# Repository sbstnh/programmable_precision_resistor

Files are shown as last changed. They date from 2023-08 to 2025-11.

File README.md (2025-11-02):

# Programmable Precision Resistor

A SCPI programmable precision resistor

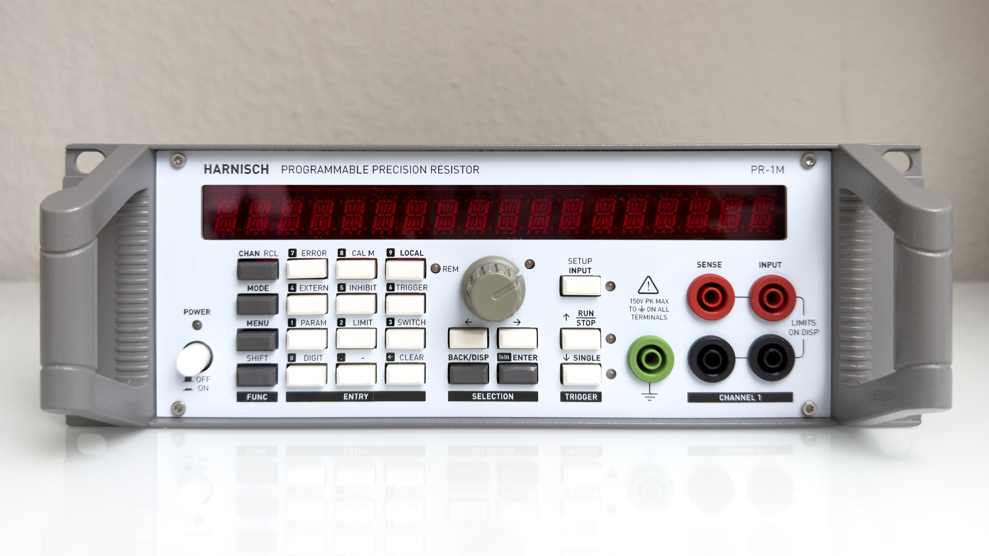
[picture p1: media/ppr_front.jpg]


**WARNING:** The programmable power resistor presented is mains powered. On the power supply board there will be mains/line voltage. Working with/on such devices can lead to damage, injury or death. Don't do it if you're not qualified or authorized to do so. You use the circuits described at you own risk. You have to make sure that the circuit is safe and adheres to the applicable standards in your location. You might operate the mainboard and ui board more safely with a bench or external power supply.

**WARNING:** I abandoned the AC/DC converter of the initial design mostly due to EMI issues. I ended up using a EI-core (isolation) transformer, bridge rectifier, capacitor two tiny DC/DC converters. Some of the documentation does not reflect this change.

## Background and motivation

In 2021/2022 I designed a DC electronic load that would be more capable, but also much more complex than the usual DIY solutions. However, after building a working breadboard prototype of the analog circuitry with 12 ICs including multiple precision and dual opamps, I thought that it might be better to start with a smaller project that would allow me to gain a lot of experience and write much of the non-application specific code that I could use later on for the digital part. Also, at the time I was looking for a decade resistor box to add to my lab. And this is how I started working on a programmable decade resistor, a pretty specialized tool for niche applications.

## Introduction

A programmable resistor is a electronic device whose electrical resistance can be adjusted typically through digital signals. Programmable resistors are available in form of integrated circuits (often referred to as digital potentiometers) as well as stand-alone devices/expansion cards. There are many different applications, each with their own set of requirements e. g.:

programmable gain amplifiers
sensor emulation, e. g. for integration tests with hardware-in-the-loop simulators
automated testing
calibrators
prototyping
Basic concept
The programmable resistor closely follows the main principle of resistor decade boxes: connecting multiple devices (“decades”) in series, with each of the devices having a settable resistance of 0 Ω, 1 ⋅ 10^n Ω, 2 ⋅ 10^n Ω, 9 ⋅ 10^n Ω, where n specifies the decade in question.

Those devices are simple resistor networks complemented by one (multi-throw) or more (single- or multi-throw) switches. While the actual topology and resistor values vary vastly, the switch(es) will always either short out or connect certain resistors or simply tap certain nodes of the resistor network. A simple implementation uses a 10-throw rotary switch to tap the nodes of a series resistor network of nine resistors.

## Features

| Parameter | Value / Description |
| :--- | :--- |
| Range | short circuit, 1 Ω … 999.999 kΩ, open circuit |
| Setpoint resolution | 1 Ω |
| Short-term setpoint accuracy estimate | <=±0.1% of value + 0.15 Ω (2W and 4W). The estimate is based on measurements for a limited number of calibration and validation resistance setpoints. The measurements were performed with an older Agilent 34401A 6.5 digit multimeter for a single DUT. This is NOT a valid strategy to get reliable/reproducible results in the sense of a specification. It's just a more or less plausible envelope based on measurements I took for my prototype. |
| Display value resolution | 6.5 digits, 5.5 digits, 4.5 digits, 3.5 digits, but not better than 1 mΩ |
| Short-term display accuracy estimate | <=±0.01% + 0.025 Ω (2W and 4W). This figure is meant to show how much the displayed resistance value (that is based on a calibration) deviates from the value shown on the DMM, the calibration has been performed with. |
| Thermal drift (estimate based on design) | <<50 ppm/K |
| Power rating | >=0.2W for decade 0 (0..9Ω),<br />>=0.5W else<br />Exact value depends on setpoint (display) |
| Bandwidth | unspecified |
| Calibration modes | - Uncalibrated: Switches are activated according to entered setpoint, display shows setpoint<br />- Two-wire (2W), Four-wire (4W): An internal setpoint is calculated based on the calibration values to reduce the error (effects changes for higher resistance values only) |
| Operating modes | Fixed: On trigger no change<br />Step: On trigger step to trigger setpoint value<br />Up: On trigger increase setpoint (linearly, 1-2-3-4-5-6-7-8-9, 1-2-5, 1-3)<br />Down: On trigger increase setpoint (linearly, 1-2-3-4-5-6-7-8-9, 1-2-5, 1-3)<br />List: See list mode |
| List mode | Up to 100 values with individual dwell times<br />- Start: on trigger; or immediately after mode selection<br />- Step:<br />  - Auto: Advance index automatically, solely based on dwell time<br />  - Trigger: Advance index on each trigger event, ignoring the dwell time<br />  - Once: Advance index on each trigger event, only after dwell time elapsed |
| Switching | fast (default), break-before-make |
| Trigger | Source: Bus, External (Rising, Falling, Either), Immediate, Manual, Timer;<br />Mode: Continuous, Single<br />Parameter: Delay, Holdoff, Time (Source: Timer) |
| Inhibit | Inhibit the input<br />- Latching: Latch input on/off on inhibit input change<br />- Live: Switch input on/off according to present inhibit input state |
| Command and trigger execution | 10ms loops |
| User interface | - 18 digit alphanumeric display:<br />  - Primary display: Resistance setpoint<br />  - Secondary display: Input state, max. current at setpoint, max. voltage at setpoint, max. power at setpoint, hardware setpoint<br />  - Menu-based<br />- 6 dual color LEDs<br />- Rotary encoder with push button<br />- 23 additional push buttons |
| User presets | 0-9; 0 is loaded on power-up |
| Interface | - USB<br />- Two digital inputs, settable polarity (positive, negative) and function (trigger, inhibit, readout) |
| Power supply | Switch mode |

## System design

System block diagram

The block diagram provides an overview of the different circuit groups of each functional block, their internal connections and external interfaces. The Programmable Decade Resistor consists of three main functional blocks:

1. Power supply (Power Supply Board), an external EMI filter is required.
2. Programmable decades, control and driver circuits (Mainboard)
3. User Interface (User Interface Board)

The power supply board uses an off-the-shelve AC/DC converter to provide a +15V rail. The +15V rail powers the relays on the mainboard as well as a DC/DC converter. A single DC/DC converter generates a +3.3V supply for both the mainboard and the UI board, including the LED display. The power rails are earth-referenced. (Nevertheless, the inputs of the Programmable Decade Resistor are floating thanks to the isolation of the relays.)

The mainboard’s main controller contains the business logic to control the relays, read the external inputs and run the USB and user interfaces. The main controller communicates with the User Interface Board over I2C which handles the multiplexing of the alphanumeric LED display, scans the switch matrix, decodes the signals of the rotary encoder and drives the buzzer.

Note that these pictures DO NOT represent the final design of the Programmable Precision Resistor and the power supply circuit in particular.
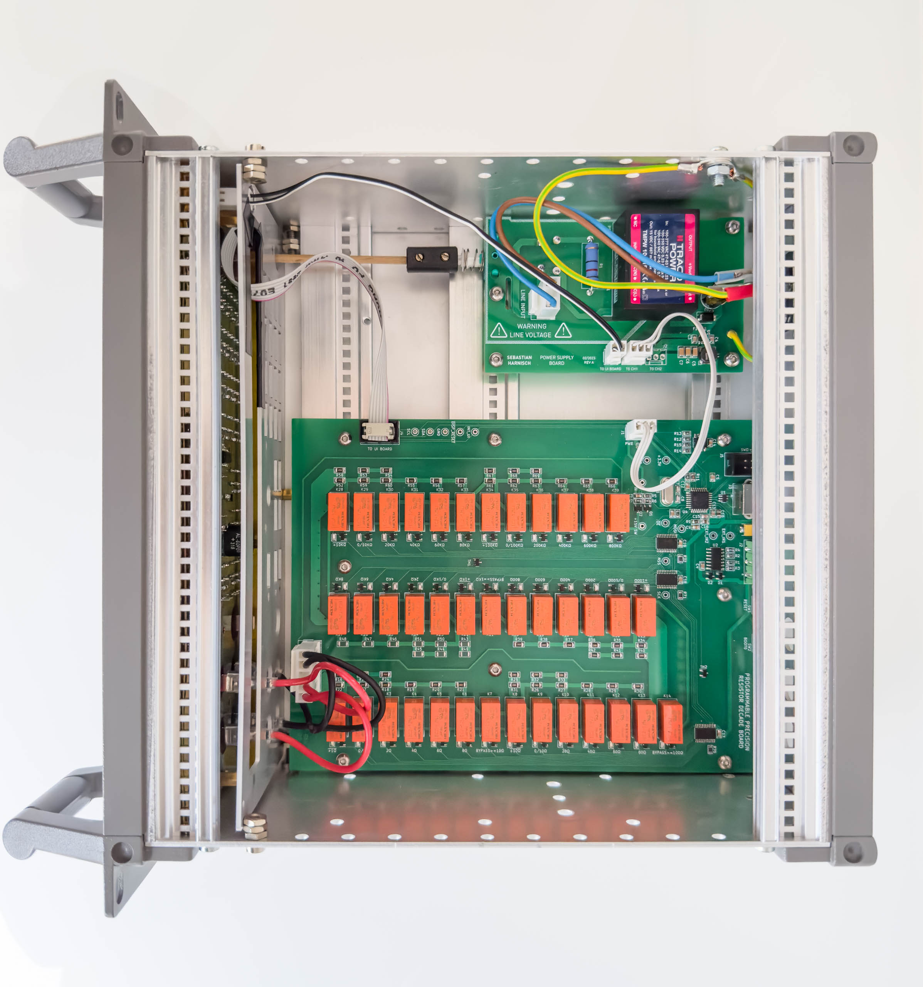
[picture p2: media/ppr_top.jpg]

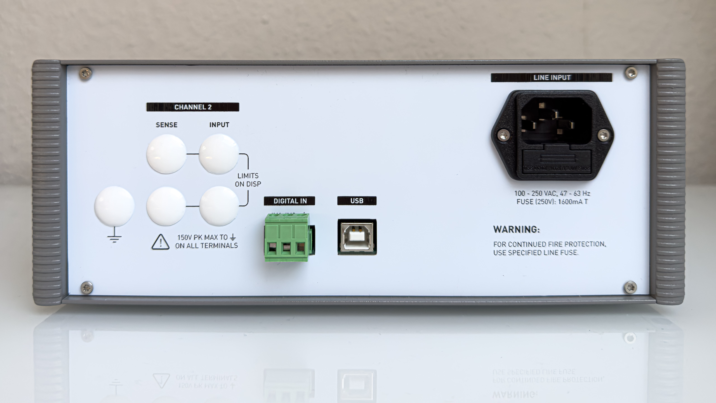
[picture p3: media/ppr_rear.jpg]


## Results

After the final calibration the results are in. The first diagram shows the absolute value of the deviation between the setpoint and the value indicated by the Agilent 34401A multimeter. Connecting lines between data points for visual purposes only.

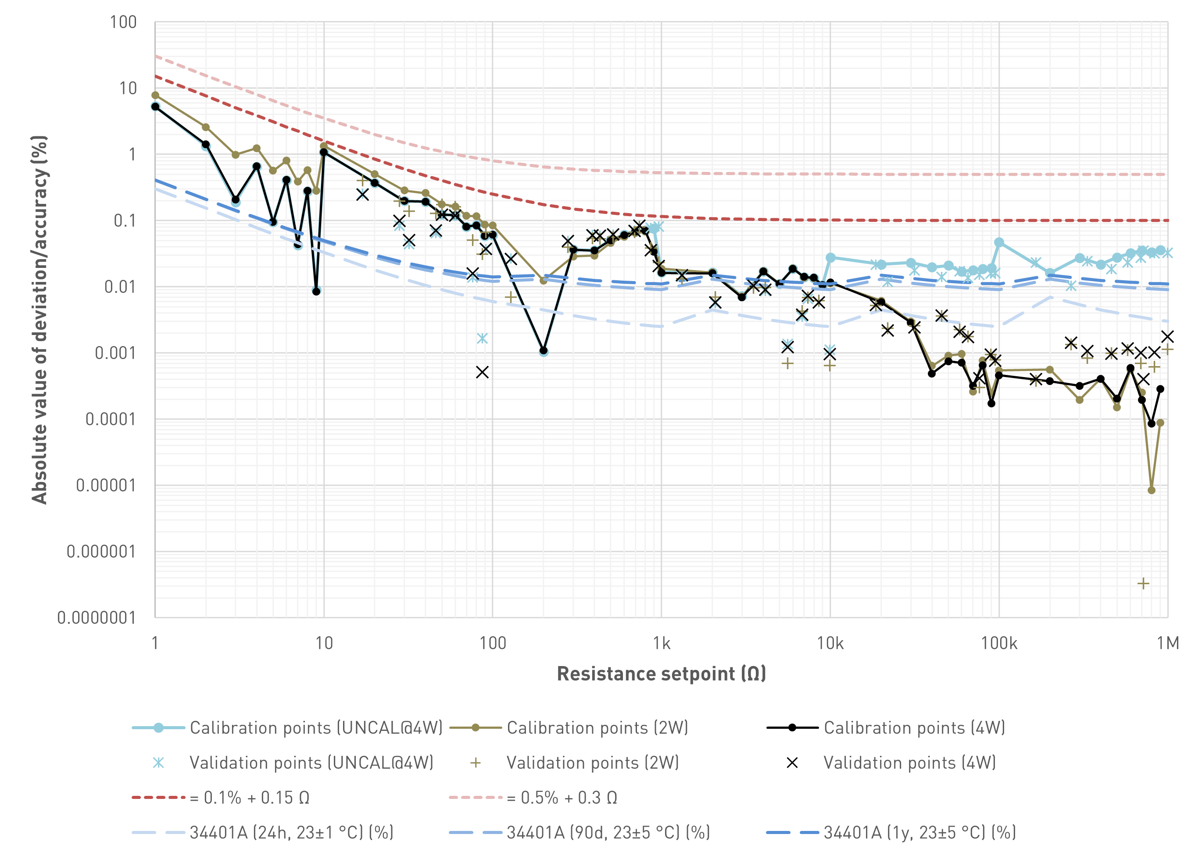
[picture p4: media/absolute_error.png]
Absolute error


The second diagram shows the absolute value of the deviation between the calculated resistance (estimate based on calibration values) and the value indicated by the Agilent 34401A multimeter. Connecting lines between data points for visual purposes only

Absolute error of indicated value

## About this repository

This repository contains the PCB design files used in this project. If you'd like to have a look at the interactive bom files you can do so here:

- Mainboard: [HTML Preview of interactive BOM](https://htmlpreview.github.io/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)
- UI board: [HTML Preview of interactive BOM](https://htmlpreview.github.io/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)
- Power Supply Board: [HTML Preview of interactive BOM](https://htmlpreview.github.io/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)

## Further information

More details are available at [https://hackaday.io/project/191969-programmable-precision-resistor](https://hackaday.io/project/191969-programmable-precision-resistor) and on my personal site [https://sebastianharnisch.de](https://sebastianharnisch.de).

## Firmware and License

The firmware was created with STM32CubeIDE and uses code auto-generated by or provided with the IDE, including
- the HAL library, code related to the USB device and other code
- FreeRTOS

Further more, this project uses a SCPI parser library that can be found here: [https://github.com/j123b567/scpi-parser](https://github.com/j123b567/scpi-parser)

Most of the auto-generated code as well as the libraries are not included here.
Therefore it is recommended to use STM32CubeIDE to create a project for the target device, with the USB device software and FreeRTOS enabled, add the required SCPI library and adapt the code according to the requirements.

For the code not included in this repository the respective licenses will apply instead of the license specified in this repository.

I DO NOT guarantee that the code provided is free of bugs (see LICENSE file for more details).

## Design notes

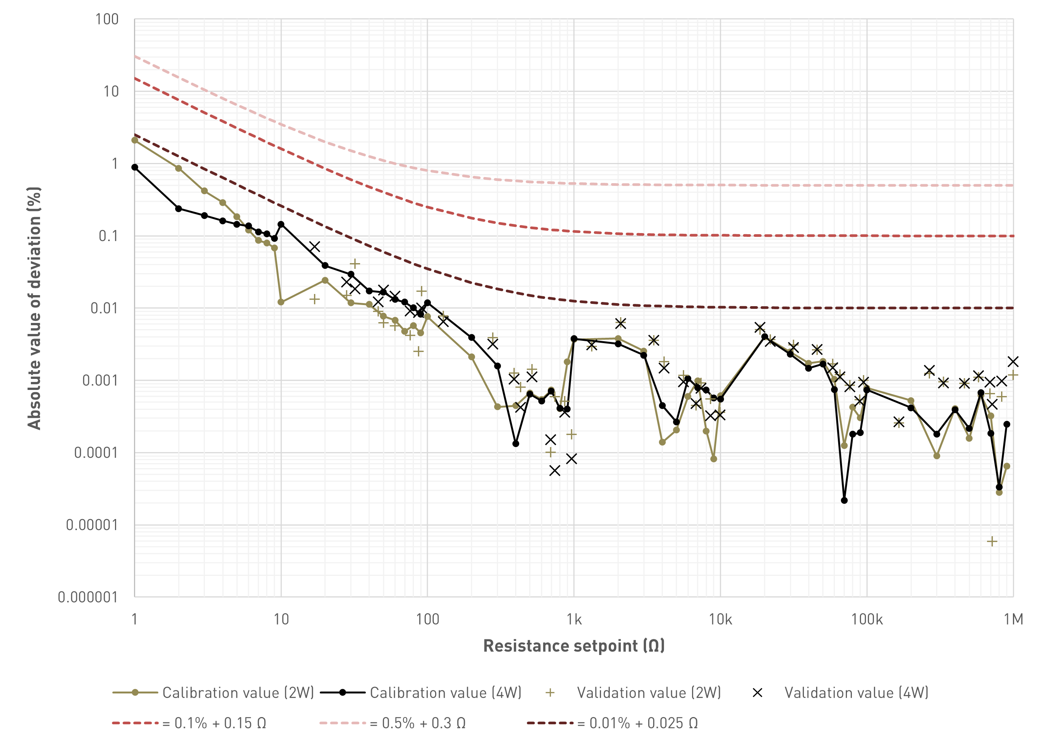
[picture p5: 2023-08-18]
media/absolute_error_calc_indicated.png

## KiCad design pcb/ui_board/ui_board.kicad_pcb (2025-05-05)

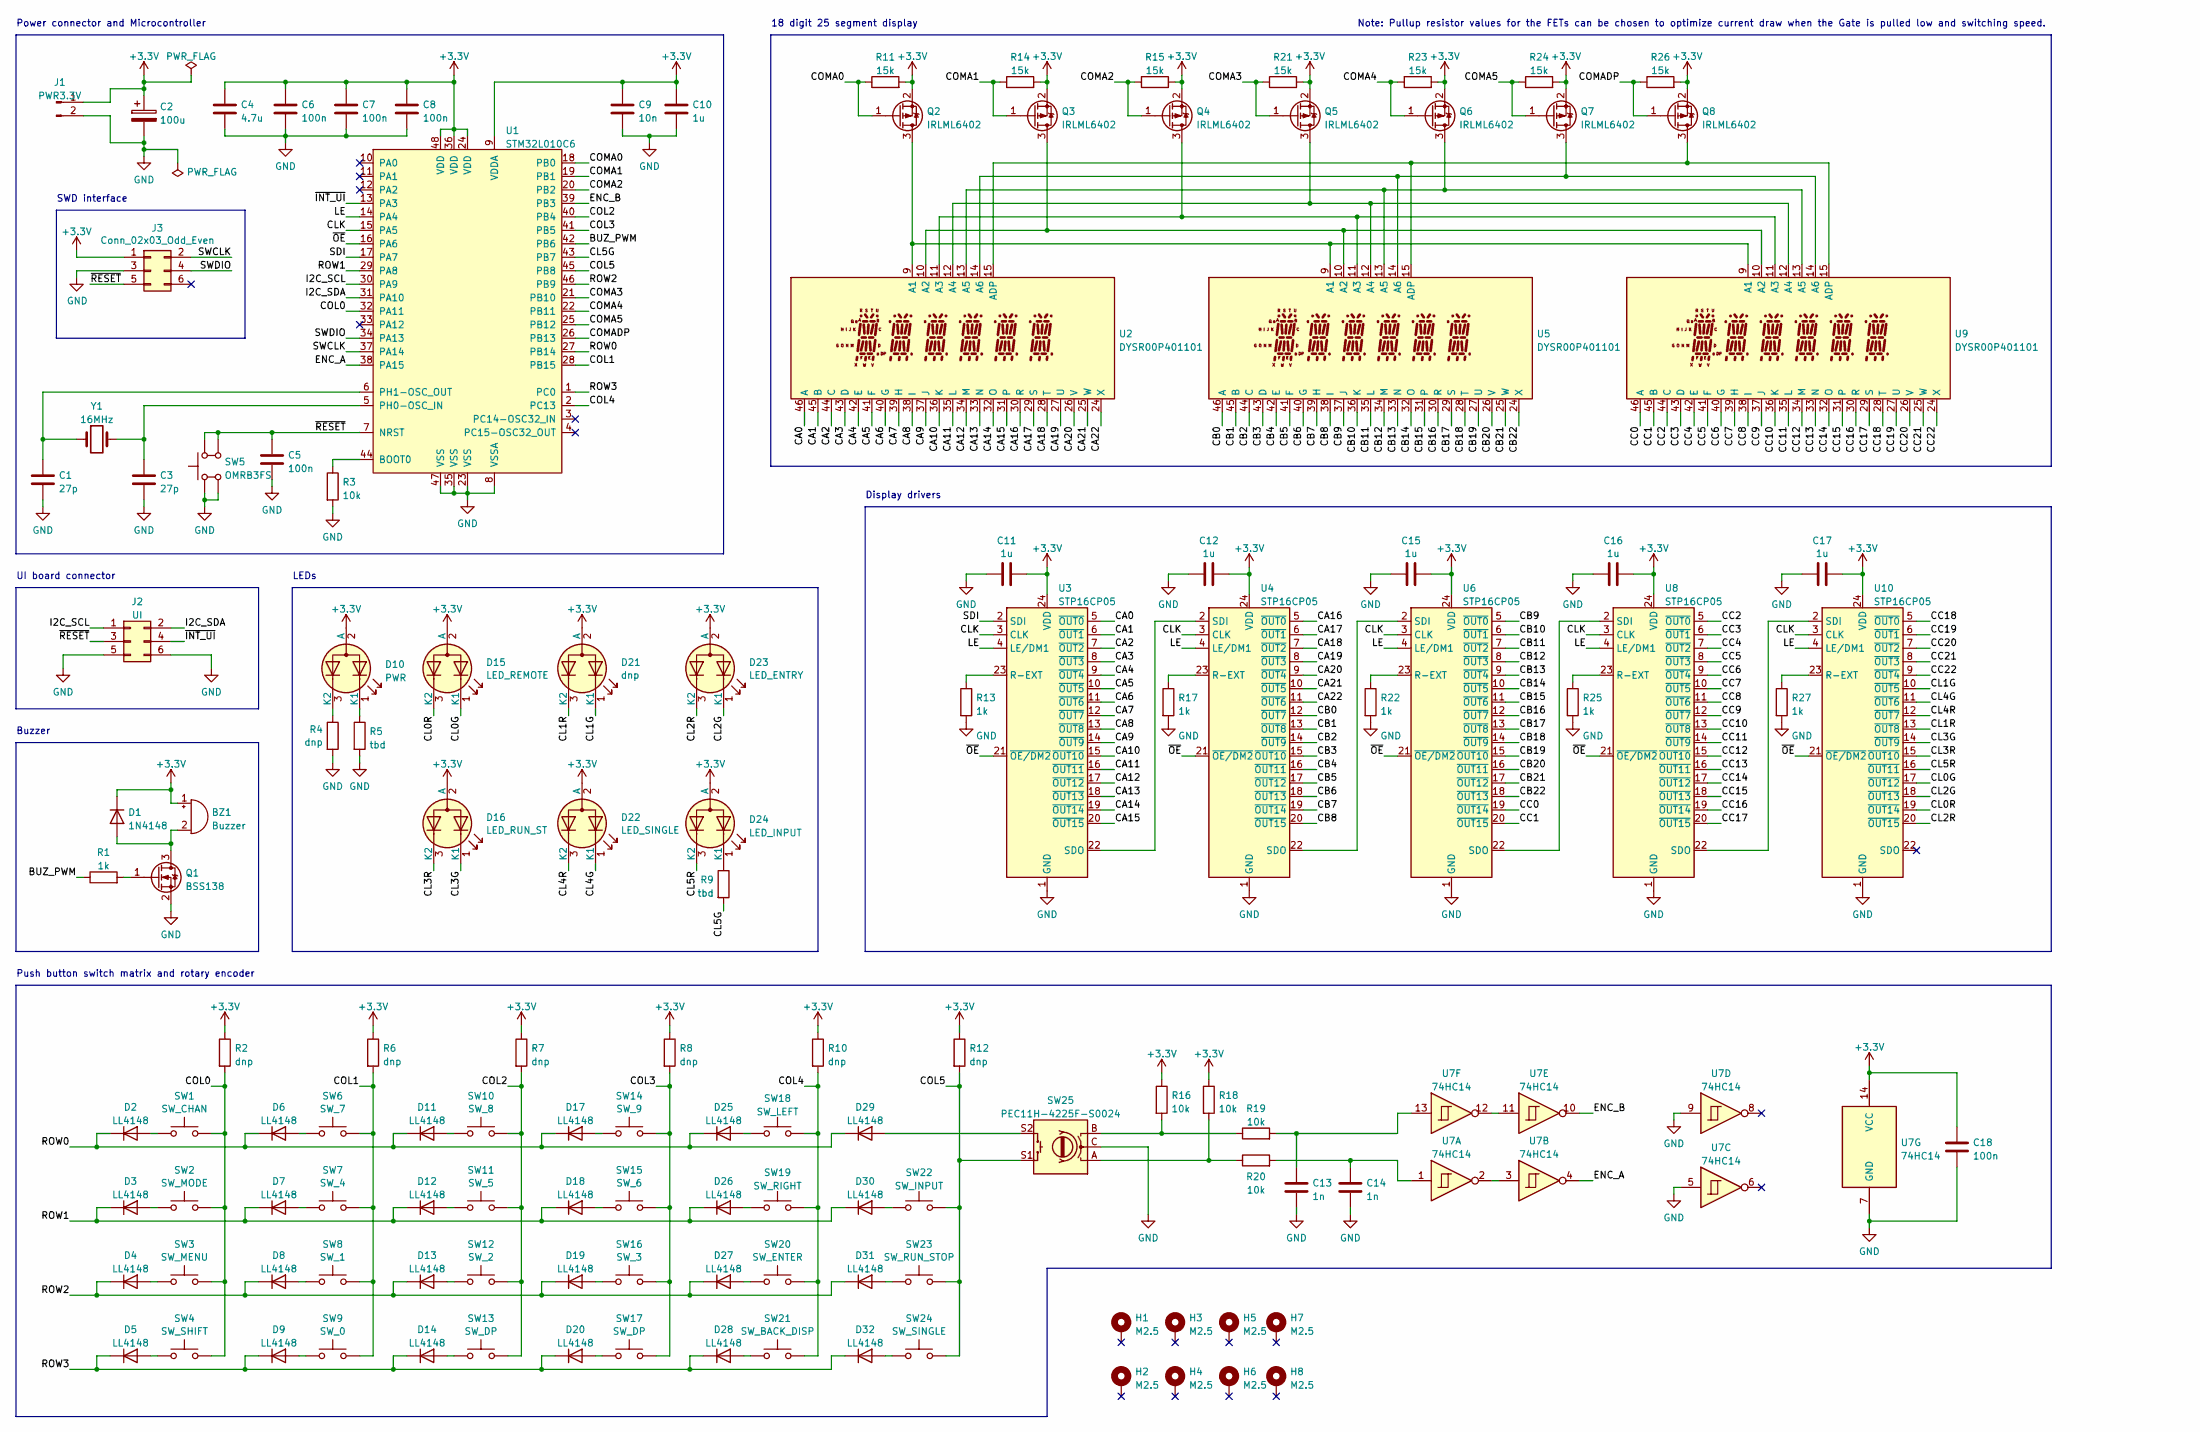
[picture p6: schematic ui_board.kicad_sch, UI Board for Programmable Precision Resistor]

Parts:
BZ1: Buzzer; Buzzer_Ekulit_AL-60P06_D12mm_H9mm
C1, C3: 27p; C_0603_1608Metric_Box
C2: 100u; CP_EIA-7343-31_Kemet-D_Pad2.25x2.55mm_HandSolder
C4: 4.7u; C_0603_1608Metric_Box
C5, C6, C7, C8, C18: 100n; C_0603_1608Metric_Box
C9: 10n; C_0603_1608Metric_Box
C10, C11, C12, C15, C16, C17: 1u; C_0603_1608Metric_Box
C13, C14: 1n; C_0603_1608Metric_Box
D1: 1N4148; D_MiniMELF
D2, D3, D4, D5, D6, D7, D8, D9, D11, D12, D13, D14, D17, D18, D19, D20, D25, D26, D27, D28, D29, D30, D31, D32: LL4148; D_MiniMELF
D10: PWR; LED_D3.0mm-3
D15: LED_REMOTE; LED_D3.0mm-3
D16: LED_RUN_ST; LED_D3.0mm-3
D21: dnp; LED_D3.0mm-3
D22: LED_SINGLE; LED_D3.0mm-3
D23: LED_ENTRY; LED_D3.0mm-3
D24: LED_INPUT; LED_D3.0mm-3
H1, H2, H3, H4, H5, H6, H7, H8: M2.5; MountingHole_2.7mm_M2.5_DIN965_Pad
J1: PWR3.3V; Molex_KK-254_AE-6410-02A_1x02_P2.54mm_Vertical
J2: UI; PinHeader_2x03_P2.54mm_Vertical
J3: Conn_02x03_Odd_Even; PinHeader_2x03_P2.54mm_Vertical
Q1: BSS138; SOT-23
Q2, Q3, Q4, Q5, Q6, Q7, Q8: IRLML6402; SOT-23
R1: 1k; R_0805_2012Metric_Box
R2, R4, R6, R7, R8, R10, R12: dnp; R_0603_1608Metric_Box
R3, R16, R18, R19, R20: 10k; R_0603_1608Metric_Box
R5, R9: tbd; R_0603_1608Metric_Box
R11, R14, R15, R21, R23, R24, R26: 15k; R_0603_1608Metric_Box
R13, R17, R22, R25, R27: 1k; R_0603_1608Metric_Box
SW1: SW_CHAN; PVA1
SW2: SW_MODE; PVA1
SW3: SW_MENU; PVA1
SW4: SW_SHIFT; PVA1
SW5: OMRB3FS; OMR_B3FS
SW6: SW_7; PVA1
SW7: SW_4; PVA1
SW8: SW_1; PVA1
SW9: SW_0; PVA1
SW10: SW_8; PVA1
SW11: SW_5; PVA1
SW12: SW_2; PVA1
SW13, SW17: SW_DP; PVA1
SW14: SW_9; PVA1
SW15: SW_6; PVA1
SW16: SW_3; PVA1
SW18: SW_LEFT; PVA1
SW19: SW_RIGHT; PVA1
SW20: SW_ENTER; PVA1
SW21: SW_BACK_DISP; PVA1
SW22: SW_INPUT; PVA1
SW23: SW_RUN_STOP; PVA1
SW24: SW_SINGLE; PVA1
SW25: PEC11H-4225F-S0024; RotaryEncoder_Alps_EC11E-Switch_Vertical_H20mm_CircularMoun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
U1: STM32L010C6; LQFP-48_7x7mm_P0.5mm
U2, U5, U9: DYSR00P401101
U3, U4, U6, U8, U10: STP16CP05; TSSOP-24_4.4x7.8mm_P0.65mm
U7: 74HC14; SO-14_3.9x8.65mm_P1.27mm
Y1: 16MHz; Crystal_HC49-4H_Vertical

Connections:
+3.3V: BZ1.1 (-), C2.1, C4.1, C6.1, C7.1, C8.1, C9.1, C10.1, C11.1, C12.1, C15.1, C16.1, C17.1, C18.1, D1.1 (K), D10.2 (A), D15.2 (A), D16.2 (A), D21.2 (A), D22.2 (A), D23.2 (A), D24.2 (A), J1.1, J3.1, Q2.2 (S), Q3.2 (S), Q4.2 (S), Q5.2 (S), Q6.2 (S), Q7.2 (S), Q8.2 (S), R2.1, R6.1, R7.1, R8.1, R10.1, R11.2, R12.1, R14.2, R15.2, R16.1, R18.1, R21.2, R23.2, R24.2, R26.2, U1.9 (VDDA), U1.24 (VDD), U1.36 (VDD), U1.48 (VDD), U3.24 (VDD), U4.24 (VDD), U6.24 (VDD), U7.14 (VCC), U8.24 (VDD), U10.24 (VDD)
/BUZ_PWM: R1.1, U1.42 (PB6)
/CA0: U2.46 (A), U3.5 (~OUT0)
/CA1: U2.45 (B), U3.6 (~OUT1)
/CA2: U2.44 (C), U3.7 (~OUT2)
/CA3: U2.43 (D), U3.8 (~OUT3)
/CA4: U2.42 (E), U3.9 (~OUT4)
/CA5: U2.41 (F), U3.10 (~OUT5)
/CA6: U2.40 (G), U3.11 (~OUT6)
/CA7: U2.39 (H), U3.12 (~OUT7)
/CA8: U2.38 (I), U3.13 (~OUT8)
/CA9: U2.37 (J), U3.14 (~OUT9)
/CA10: U2.36 (K), U3.15 (~OUT10)
/CA11: U2.35 (L), U3.16 (~OUT11)
/CA12: U2.34 (M), U3.17 (~OUT12)
/CA13: U2.33 (N), U3.18 (~OUT13)
/CA14: U2.32 (O), U3.19 (~OUT14)
/CA15: U2.31, U3.20 (~OUT15)
/CA16: U2.30 (R), U4.5 (~OUT0)
/CA17: U2.29 (S), U4.6 (~OUT1)
/CA18: U2.28 (T), U4.7 (~OUT2)
/CA19: U2.27 (U), U4.8 (~OUT3)
/CA20: U2.26 (V), U4.9 (~OUT4)
/CA21: U2.25 (W), U4.10 (~OUT5)
/CA22: U2.24 (X), U4.11 (~OUT6)
/CB0: U4.12 (~OUT7), U5.46 (A)
/CB1: U4.13 (~OUT8), U5.45 (B)
/CB2: U4.14 (~OUT9), U5.44 (C)
/CB3: U4.15 (~OUT10), U5.43 (D)
/CB4: U4.16 (~OUT11), U5.42 (E)
/CB5: U4.17 (~OUT12), U5.41 (F)
/CB6: U4.18 (~OUT13), U5.40 (G)
/CB7: U4.19 (~OUT14), U5.39 (H)
/CB8: U4.20 (~OUT15), U5.38 (I)
/CB9: U5.37 (J), U6.5 (~OUT0)
/CB10: U5.36 (K), U6.6 (~OUT1)
/CB11: U5.35 (L), U6.7 (~OUT2)
/CB12: U5.34 (M), U6.8 (~OUT3)
/CB13: U5.33 (N), U6.9 (~OUT4)
/CB14: U5.32 (O), U6.10 (~OUT5)
/CB15: U5.31, U6.11 (~OUT6)
/CB16: U5.30 (R), U6.12 (~OUT7)
/CB17: U5.29 (S), U6.13 (~OUT8)
/CB18: U5.28 (T), U6.14 (~OUT9)
/CB19: U5.27 (U), U6.15 (~OUT10)
/CB20: U5.26 (V), U6.16 (~OUT11)
/CB21: U5.25 (W), U6.17 (~OUT12)
/CB22: U5.24 (X), U6.18 (~OUT13)
/CC0: U6.19 (~OUT14), U9.46 (A)
/CC1: U6.20 (~OUT15), U9.45 (B)
/CC2: U8.5 (~OUT0), U9.44 (C)
/CC3: U8.6 (~OUT1), U9.43 (D)
/CC4: U8.7 (~OUT2), U9.42 (E)
/CC5: U8.8 (~OUT3), U9.41 (F)
/CC6: U8.9 (~OUT4), U9.40 (G)
/CC7: U8.10 (~OUT5), U9.39 (H)
/CC8: U8.11 (~OUT6), U9.38 (I)
/CC9: U8.12 (~OUT7), U9.37 (J)
/CC10: U8.13 (~OUT8), U9.36 (K)
/CC11: U8.14 (~OUT9), U9.35 (L)
/CC12: U8.15 (~OUT10), U9.34 (M)
/CC13: U8.16 (~OUT11), U9.33 (N)
/CC14: U8.17 (~OUT12), U9.32 (O)
/CC15: U8.18 (~OUT13), U9.31
/CC16: U8.19 (~OUT14), U9.30 (R)
/CC17: U8.20 (~OUT15), U9.29 (S)
/CC18: U9.28 (T), U10.5 (~OUT0)
/CC19: U9.27 (U), U10.6 (~OUT1)
/CC20: U9.26 (V), U10.7 (~OUT2)
/CC21: U9.25 (W), U10.8 (~OUT3)
/CC22: U9.24 (X), U10.9 (~OUT4)
/CL0G: D15.1 (K1), U10.17 (~OUT12)
/CL0R: D15.3 (K2), U10.19 (~OUT14)
/CL1G: D21.1 (K1), U10.10 (~OUT5)
/CL1R: D21.3 (K2), U10.13 (~OUT8)
/CL2G: D23.1 (K1), U10.18 (~OUT13)
/CL2R: D23.3 (K2), U10.20 (~OUT15)
/CL3G: D16.1 (K1), U10.14 (~OUT9)
/CL3R: D16.3 (K2), U10.15 (~OUT10)
/CL4G: D22.1 (K1), U10.11 (~OUT6)
/CL4R: D22.3 (K2), U10.12 (~OUT7)
/CL5G: R9.2, U1.43 (PB7)
/CL5R: D24.3 (K2), U10.16 (~OUT11)
/CLK: U1.15 (PA5), U3.3 (CLK), U4.3 (CLK), U6.3 (CLK), U8.3 (CLK), U10.3 (CLK)
/COL0: R2.2, SW1.2, SW2.2, SW3.2, SW4.2, U1.32 (PA11)
/COL1: R6.2, SW6.2, SW7.2, SW8.2, SW9.2, U1.28 (PB15)
/COL2: R7.2, SW10.2, SW11.2, SW12.2, SW13.2, U1.40 (PB4)
/COL3: R8.2, SW14.2, SW15.2, SW16.2, SW17.2, U1.41 (PB5)
/COL4: R10.2, SW18.2, SW19.2, SW20.2, SW21.2, U1.2 (PC13)
/COL5: R12.2, SW22.2, SW23.2, SW24.2, SW25.S1, U1.45 (PB8)
/COMA0: Q2.1 (G), R11.1, U1.18 (PB0)
/COMA1: Q3.1 (G), R14.1, U1.19 (PB1)
/COMA2: Q4.1 (G), R15.1, U1.20 (PB2)
/COMA3: Q5.1 (G), R21.1, U1.21 (PB10)
/COMA4: Q6.1 (G), R23.1, U1.22 (PB11)
/COMA5: Q7.1 (G), R24.1, U1.25 (PB12)
/COMADP: Q8.1 (G), R26.1, U1.26 (PB13)
/ENC_A: U1.38 (PA15), U7.4
/ENC_B: U1.39 (PB3), U7.10
/I2C_SCL: J2.1, U1.30 (PA9)
/I2C_SDA: J2.2, U1.31 (PA10)
/LE: U1.14 (PA4), U3.4 (LE/DM1), U4.4 (LE/DM1), U6.4 (LE/DM1), U8.4 (LE/DM1), U10.4 (LE/DM1)
/ROW0: D2.1 (K), D6.1 (K), D11.1 (K), D17.1 (K), D25.1 (K), D29.1 (K), U1.27 (PB14)
/ROW1: D3.1 (K), D7.1 (K), D12.1 (K), D18.1 (K), D26.1 (K), D30.1 (K), U1.29 (PA8)
/ROW2: D4.1 (K), D8.1 (K), D13.1 (K), D19.1 (K), D27.1 (K), D31.1 (K), U1.46 (PB9)
/ROW3: D5.1 (K), D9.1 (K), D14.1 (K), D20.1 (K), D28.1 (K), D32.1 (K), U1.1 (PC0)
/SDI: U1.17 (PA7), U3.2 (SDI)
/SWCLK: J3.2, U1.37 (PA14)
/SWDIO: J3.4, U1.34 (PA13)
/~INT_UI: J2.4, U1.13 (PA3)
/~OE: U1.16 (PA6), U3.21 (~OE/DM2), U4.21 (~OE/DM2), U6.21 (~OE/DM2), U8.21 (~OE/DM2), U10.21 (~OE/DM2)
/~RESET: C5.1, J2.3, J3.5, SW5.3, SW5.4, U1.7 (NRST)
GND: C1.2, C2.2, C3.2, C4.2, C5.2, C6.2, C7.2, C8.2, C9.2, C10.2, C11.2, C12.2, C13.2, C14.2, C15.2, C16.2, C17.2, C18.2, J1.2, J2.5, J2.6, J3.3, Q1.2 (S), R3.2, R4.2, R5.2, R13.2, R17.2, R22.2, R25.2, R27.2, SW5.1, SW5.2, SW25.C, U1.8 (VSSA), U1.23 (VSS), U1.35 (VSS), U1.47 (VSS), U3.1 (GND), U4.1 (GND), U6.1 (GND), U7.5, U7.7 (GND), U7.9, U8.1 (GND), U10.1 (GND)
unnamed: BZ1.2 (+), D1.2 (A), Q1.3 (D)
unnamed: C13.1, R19.2, U7.13
unnamed: C14.1, R20.2, U7.1
unnamed: D2.2 (A), SW1.1
unnamed: D3.2 (A), SW2.1
unnamed: D4.2 (A), SW3.1
unnamed: D5.2 (A), SW4.1
unnamed: D6.2 (A), SW6.1
unnamed: D7.2 (A), SW7.1
unnamed: D8.2 (A), SW8.1
unnamed: D9.2 (A), SW9.1
unnamed: D10.1 (K1), R5.1
unnamed: D10.3 (K2), R4.1
unnamed: D11.2 (A), SW10.1
unnamed: D12.2 (A), SW11.1
unnamed: D13.2 (A), SW12.1
unnamed: D14.2 (A), SW13.1
unnamed: D17.2 (A), SW14.1
unnamed: D18.2 (A), SW15.1
unnamed: D19.2 (A), SW16.1
unnamed: D20.2 (A), SW17.1
unnamed: D24.1 (K1), R9.1
unnamed: D25.2 (A), SW18.1
unnamed: D26.2 (A), SW19.1
unnamed: D27.2 (A), SW20.1
unnamed: D28.2 (A), SW21.1
unnamed: D29.2 (A), SW25.S2
unnamed: D30.2 (A), SW22.1
unnamed: D31.2 (A), SW23.1
unnamed: D32.2 (A), SW24.1
unnamed: Q1.1 (G), R1.2
unnamed: Q2.3 (D), U2.9 (A1), U5.9 (A1), U9.9 (A1)
unnamed: Q3.3 (D), U2.10 (A2), U5.10 (A2), U9.10 (A2)
unnamed: Q4.3 (D), U2.11 (A3), U5.11 (A3), U9.11 (A3)
unnamed: Q5.3 (D), U2.12 (A4), U5.12 (A4), U9.12 (A4)
unnamed: Q6.3 (D), U2.13 (A5), U5.13 (A5), U9.13 (A5)
unnamed: Q7.3 (D), U2.14 (A6), U5.14 (A6), U9.14 (A6)
unnamed: Q8.3 (D), U2.15 (ADP), U5.15 (ADP), U9.15 (ADP)
unnamed: R16.2, R19.1, SW25.B
unnamed: R18.2, R20.1, SW25.A
unnamed: R3.1, U1.44 (BOOT0)
unnamed: C3.1, U1.5 (PH0-OSC_IN), Y1.2
unnamed: C1.1, U1.6 (PH1-OSC_OUT), Y1.1
unnamed: R13.1, U3.23 (R-EXT)
unnamed: U3.22 (SDO), U4.2 (SDI)
unnamed: R17.1, U4.23 (R-EXT)
unnamed: U4.22 (SDO), U6.2 (SDI)
unnamed: R22.1, U6.23 (R-EXT)
unnamed: U6.22 (SDO), U8.2 (SDI)
unnamed: U7.2, U7.3
unnamed: U7.11, U7.12
unnamed: R25.1, U8.23 (R-EXT)
unnamed: R27.1, U10.23 (R-EXT)
unnamed: U8.22 (SDO), U10.2 (SDI)

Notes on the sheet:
Push button switch matrix and rotary encoder
Display drivers
18 digit 25 segment display
SWD interface
LEDs
Power connector and Microcontroller
UI board connector
Buzzer
Note: Pullup resistor values for the FETs can be chosen to optimize current draw when the Gate is pulled low and switching speed.

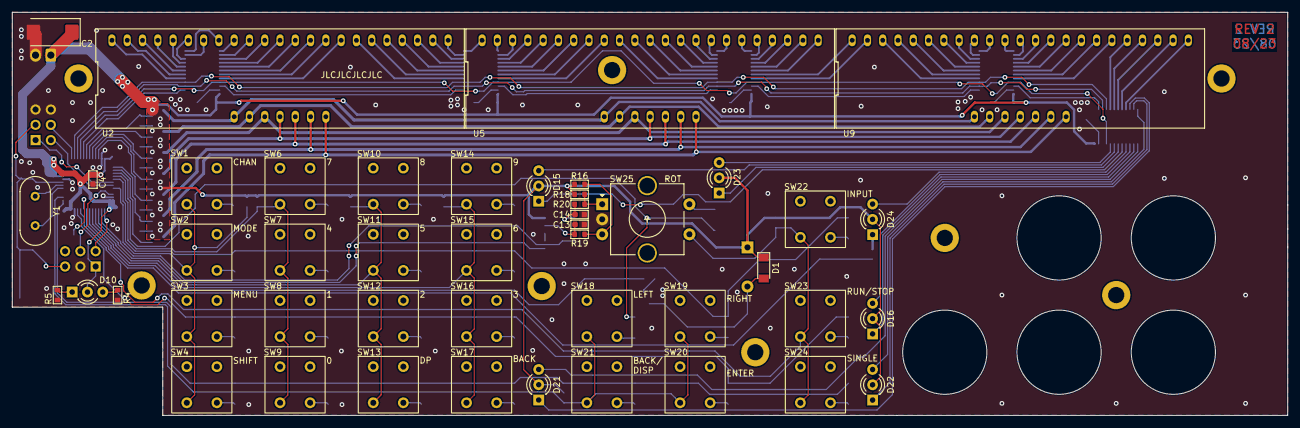
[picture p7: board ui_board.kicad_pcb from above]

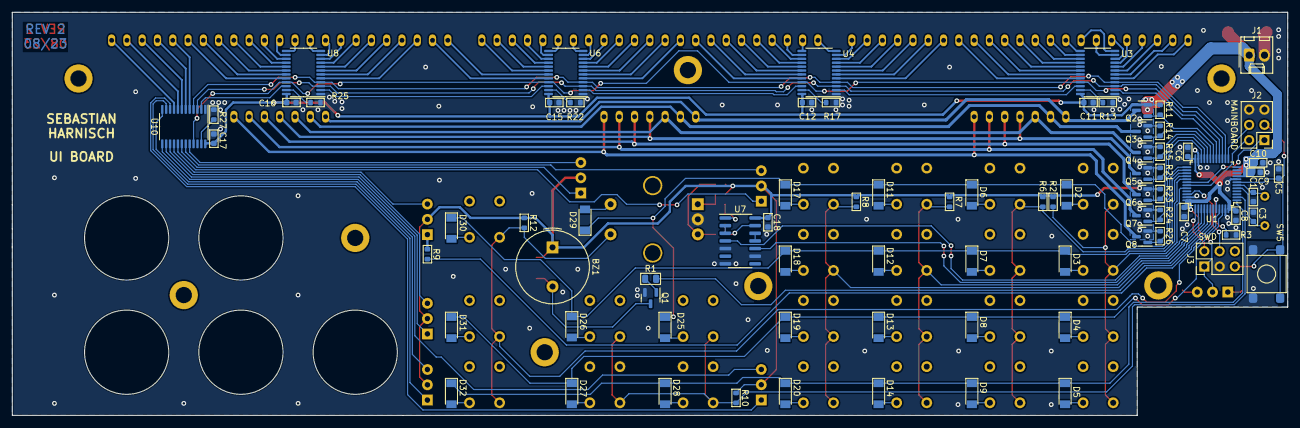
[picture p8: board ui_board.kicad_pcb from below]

Board: 2 copper layers, 212.0 x 67.0 mm, 133 parts (79 on the bottom side), 167 nets.

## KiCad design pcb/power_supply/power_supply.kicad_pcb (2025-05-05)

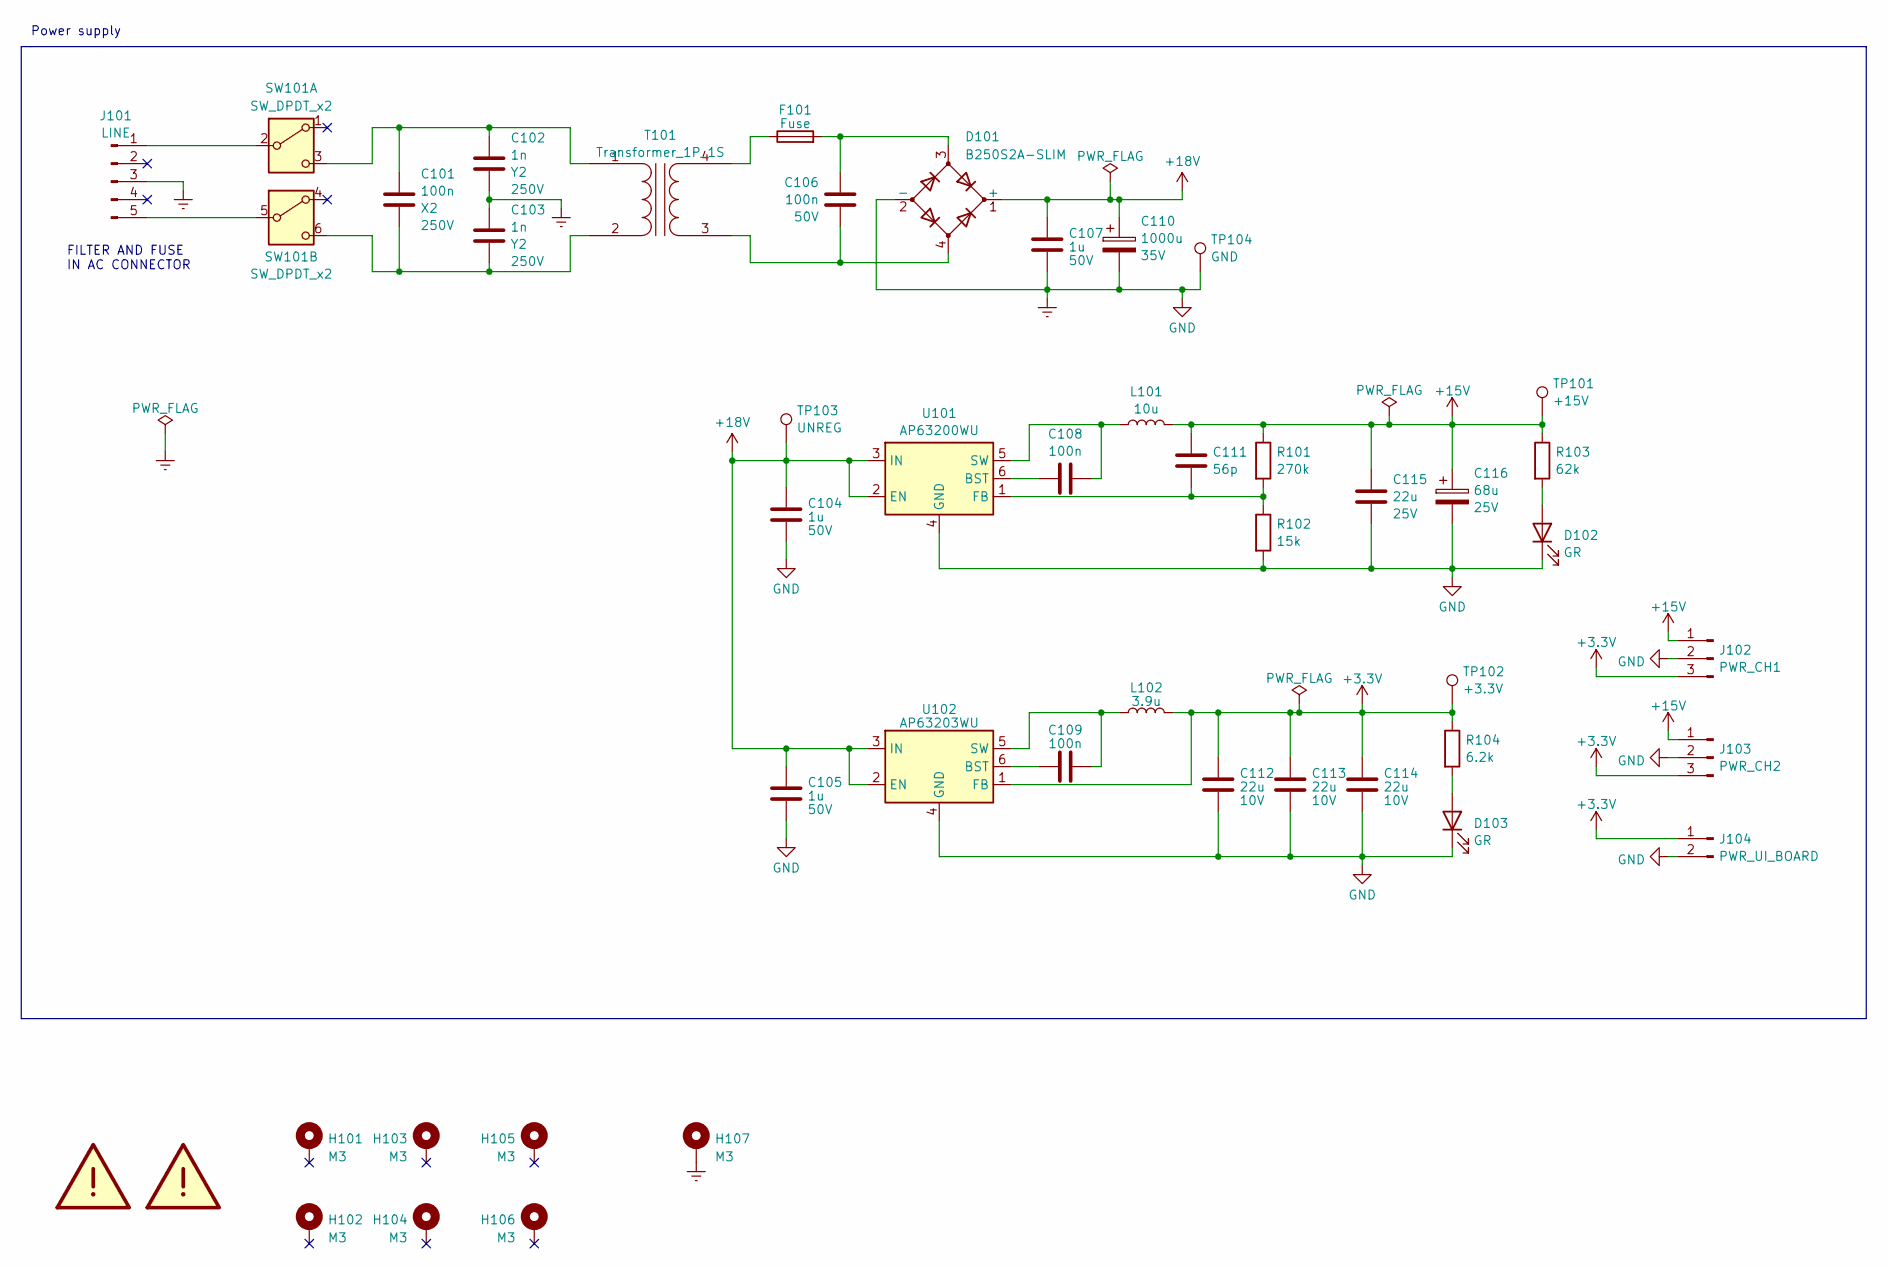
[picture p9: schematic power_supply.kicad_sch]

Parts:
C101: 100n; C_Rect_L18.0mm_W5.0mm_P15.00mm_FKS3_FKP3; Voltage Rating 250V
C102, C103: 1n; C_Rect_L13.5mm_W5.0mm_P10.00mm_FKS3_FKP3_MKS4; Voltage Rating 250V
C104, C105: 1u; C_1206_3216Metric; Voltage Rating 50V
C106: 100n; C_0805_2012Metric; Voltage Rating 50V
C107: 1u; C_0805_2012Metric; Voltage Rating 50V
C108, C109: 100n; C_0603_1608Metric
C110: 1000u; CP_Radial_D16.0mm_P7.50mm; Voltage Rating 35V
C111: 56p; C_0603_1608Metric
C112, C113, C114: 22u; C_1206_3216Metric; Voltage Rating 10V
C115: 22u; C_1206_3216Metric; Voltage Rating 25V
C116: 68u; C_Elec_6.3x5.8; Voltage Rating 25V
D101: B250S2A-SLIM; Diode_Bridge_Diotec_SO-DIL-Slim
D102, D103: GR; LED_0603_1608Metric
F101: Fuse; Fuse_1206_3216Metric
H101, H102, H103, H104, H105, H106: M3; MountingHole_3.2mm_M3_DIN965_Pad
H107: M3; MountingHole_2.2mm_M2_DIN965_Pad
J101: LINE; Molex_KK-396_A-41791-0005_1x05_P3.96mm_Vertical
J102: PWR_CH1; Molex_KK-254_AE-6410-03A_1x03_P2.54mm_Vertical
J103: PWR_CH2; Molex_KK-254_AE-6410-03A_1x03_P2.54mm_Vertical
J104: PWR_UI_BOARD; Molex_KK-254_AE-6410-02A_1x02_P2.54mm_Vertical
L101: 10u; L_Bourns-SRN4018
L102: 3.9u; L_Bourns-SRN4018
LOGO101, LOGO102: SYMBOL_TRIANGLE_WARNING; Triangle_Warning
R101: 270k; R_0603_1608Metric
R102: 15k; R_0603_1608Metric
R103: 62k; R_0603_1608Metric
R104: 6.2k; R_0603_1608Metric
SW101: SW_DPDT_x2; NE1848EE
T101: Transformer_1P_1S; BLOCK_VC16_1
TP101: +15V; TestPoint_Keystone_5000-5004_Miniature
TP102: +3.3V; TestPoint_Keystone_5000-5004_Miniature
TP103: UNREG; TestPoint_Keystone_5000-5004_Miniature
TP104: GND; TestPoint_Keystone_5000-5004_Miniature
U101: AP63200WU; TSOT-23-6
U102: AP63203WU; TSOT-23-6

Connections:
+3.3V: C112.1, C113.1, C114.1, J102.3, J103.3, J104.1, L102.2, R104.1, TP102.1, U102.1 (FB)
+15V: C111.2, C115.1, C116.1, J102.1, J103.1, L101.2, R101.1, R103.1, TP101.1
+18V: C104.1, C105.1, C107.1, C110.1, D101.1 (+), TP103.1, U101.2 (EN), U101.3 (IN), U102.2 (EN), U102.3 (IN)
Earth: C102.2, C103.1, C104.2, C105.2, C107.2, C110.2, C112.2, C113.2, C114.2, C115.2, C116.2, D101.2 (-), D102.1 (K), D103.1 (K), H107.1, J101.3, J102.2, J103.2, J104.2, R102.2, TP104.1, U101.4 (GND), U102.4 (GND)
unnamed: C106.1, D101.3, F101.2
unnamed: D102.2 (A), R103.2
unnamed: D103.2 (A), R104.2
unnamed: J101.1, SW101.2 (B)
unnamed: J101.5, SW101.5 (B)
unnamed: C101.1, C102.1, SW101.3 (C), T101.1 (AA)
unnamed: C101.2, C103.2, SW101.6 (C), T101.2 (AB)
unnamed: C106.2, D101.4, T101.3 (SA)
unnamed: F101.1, T101.4 (SB)
unnamed: C108.1, U101.6 (BST)
unnamed: C111.1, R101.2, R102.1, U101.1 (FB)
unnamed: C108.2, L101.1, U101.5 (SW)
unnamed: C109.1, U102.6 (BST)
unnamed: C109.2, L102.1, U102.5 (SW)

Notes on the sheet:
Power supply
FILTER AND FUSE IN AC CONNECTOR

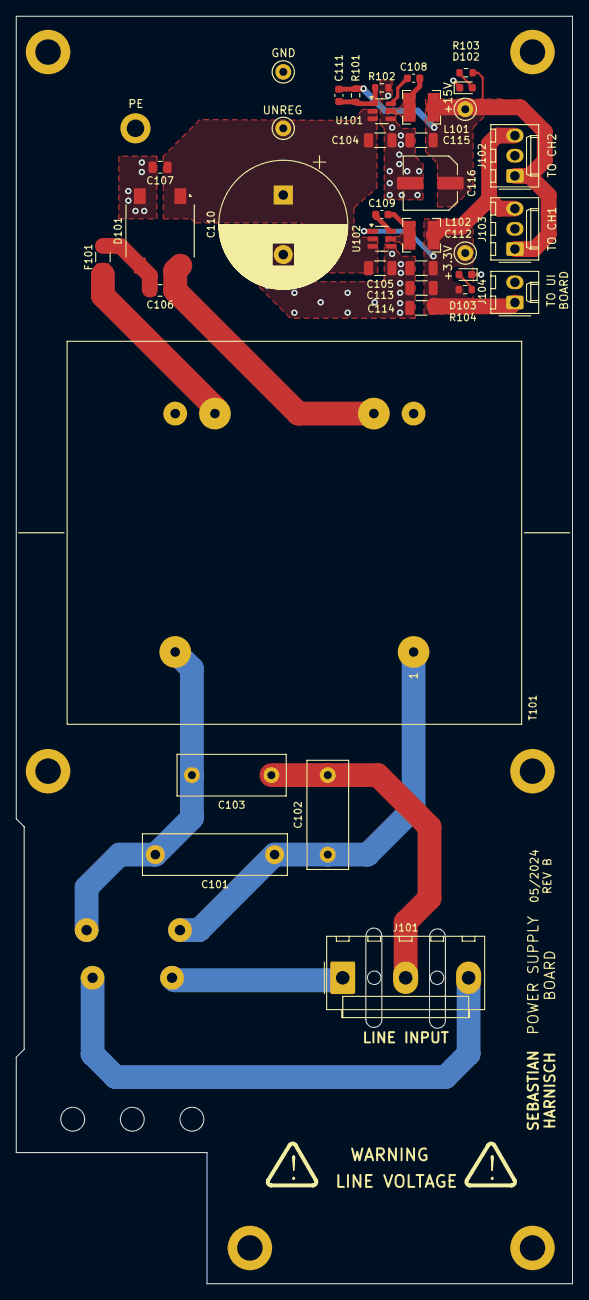
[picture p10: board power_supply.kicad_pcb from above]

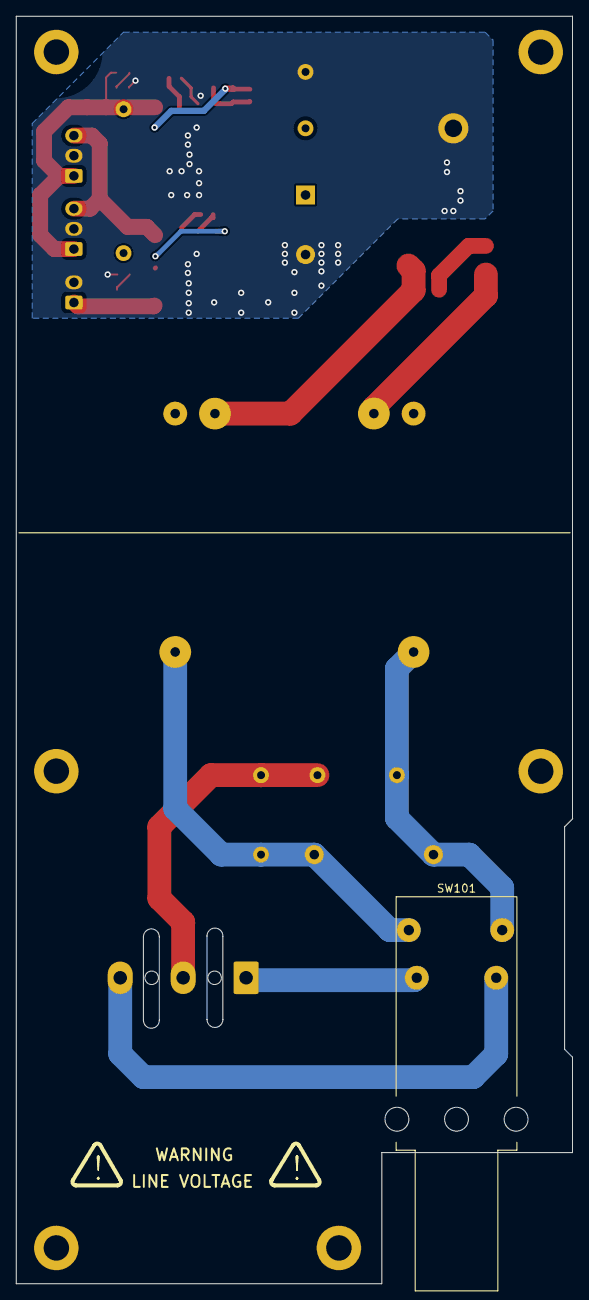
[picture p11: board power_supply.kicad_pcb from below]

Board: 2 copper layers, 70.0 x 159.5 mm, 49 parts (3 on the bottom side), 18 nets.

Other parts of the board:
LOGO101#2, LOGO101#3: SYMBOL_TRIANGLE_WARNING; Triangle_Warning

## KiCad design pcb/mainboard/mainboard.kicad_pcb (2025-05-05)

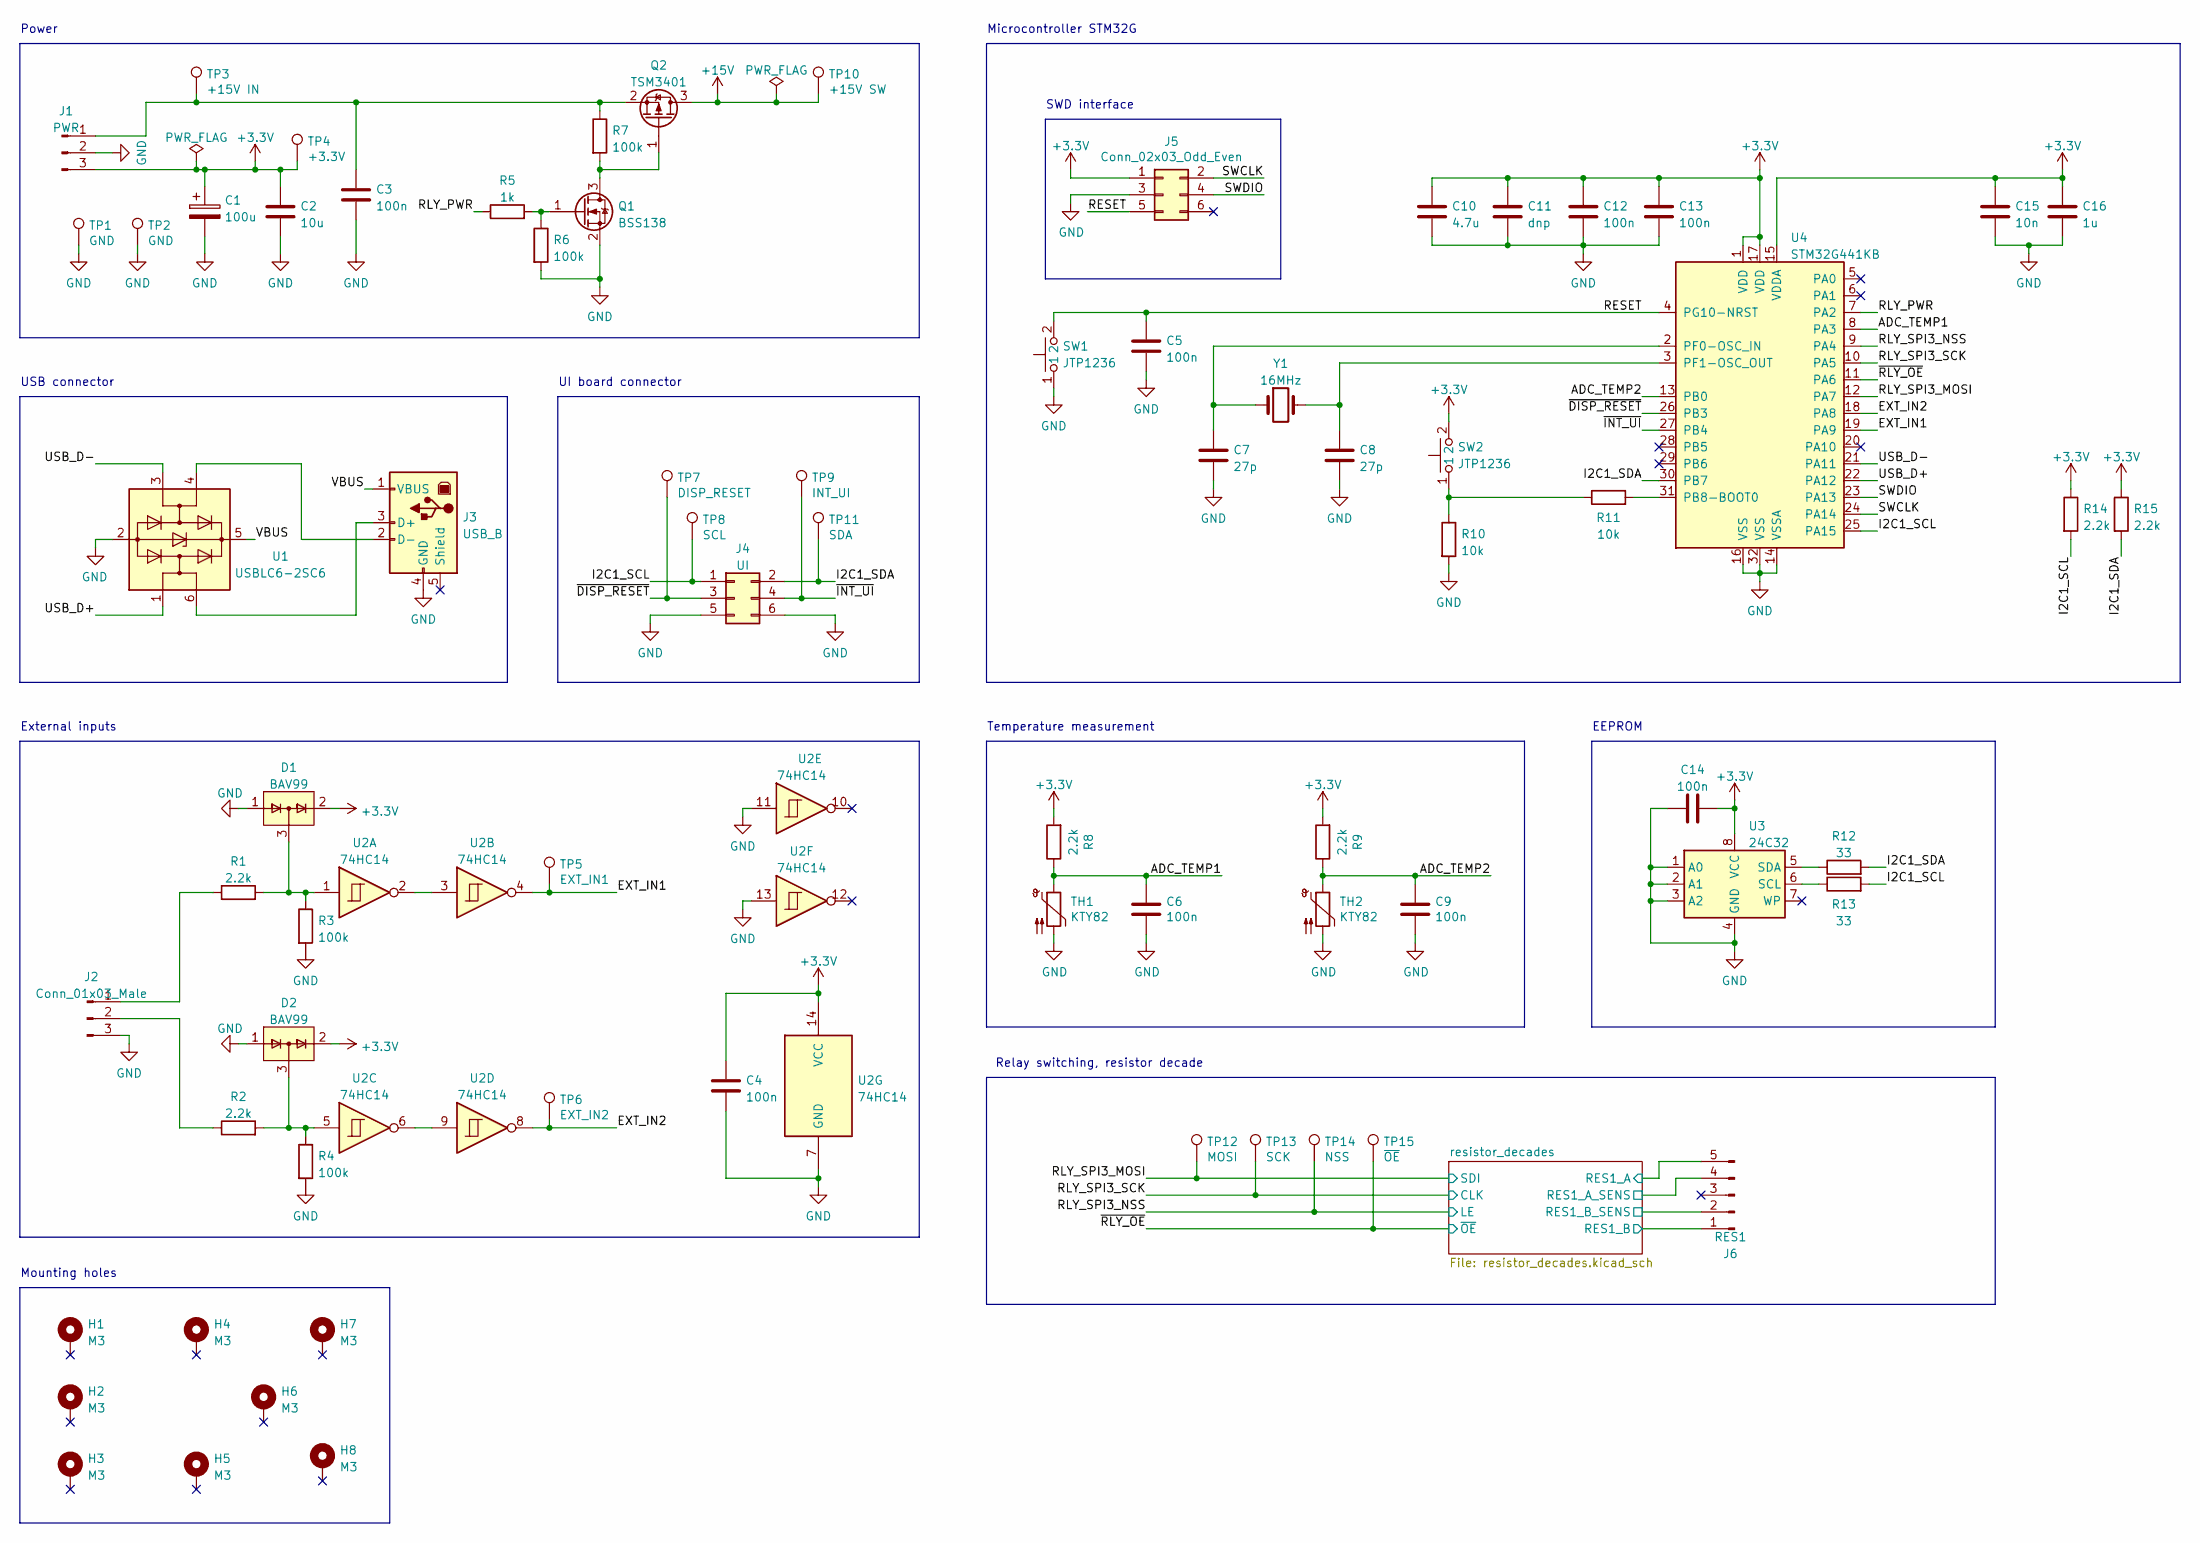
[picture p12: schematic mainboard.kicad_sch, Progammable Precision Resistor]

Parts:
C1: 100u; CP_EIA-7343-31_Kemet-D_Pad2.25x2.55mm_HandSolder
C2: 10u; C_0805_2012Metric_Box
C3, C4, C5, C6, C9, C12, C13, C14: 100n; C_0805_2012Metric_Box
C7, C8: 27p; C_0805_2012Metric_Box
C10: 4.7u; C_0805_2012Metric_Box
C11: dnp; C_0805_2012Metric_Box
C15: 10n; C_0805_2012Metric_Box
C16: 1u; C_0805_2012Metric_Box
D1, D2: BAV99; SOT-23
H1, H2, H3, H4, H5, H6, H7, H8: M3; MountingHole_3.2mm_M3_DIN965_Pad
J1: PWR; Molex_KK-254_AE-6410-03A_1x03_P2.54mm_Vertical
J2: Conn_01x03_Male; PhoenixContact_MSTBA_2,5_3-G_1x03_P5.00mm_Horizontal
J3: USB_B; USB_B_Lumberg_2411_02_Horizontal
J4: UI; IDC-Header_2x03_P2.54mm_Vertical
J5: Conn_02x03_Odd_Even; IDC-Header_2x03_P2.54mm_Vertical
J6: RES1; Molex_KK-396_A-41791-0005_1x05_P3.96mm_Vertical
Q1: BSS138; SOT-23
Q2: TSM3401; SOT-23
R1, R2, R8, R9, R14, R15: 2.2k; R_0805_2012Metric_Box
R3, R4, R6, R7: 100k; R_0805_2012Metric_Box
R5: 1k; R_0805_2012Metric_Box
R10, R11: 10k; R_0805_2012Metric_Box
R12, R13: 33; R_0805_2012Metric_Box
SW1, SW2: JTP1236
TH1, TH2: KTY82; SOT-23
TP1, TP2: GND; TestPoint_Loop_D1.80mm_Drill1.0mm_Beaded
TP3: +15V IN; TestPoint_Loop_D1.80mm_Drill1.0mm_Beaded
TP4: +3.3V; TestPoint_Loop_D1.80mm_Drill1.0mm_Beaded
TP5: EXT_IN1; TestPoint_Loop_D1.80mm_Drill1.0mm_Beaded
TP6: EXT_IN2; TestPoint_Loop_D1.80mm_Drill1.0mm_Beaded
TP7: DISP_RESET; TestPoint_Loop_D1.80mm_Drill1.0mm_Beaded
TP8: SCL; TestPoint_Loop_D1.80mm_Drill1.0mm_Beaded
TP9: INT_UI; TestPoint_Loop_D1.80mm_Drill1.0mm_Beaded
TP10: +15V SW; TestPoint_Loop_D1.80mm_Drill1.0mm_Beaded
TP11: SDA; TestPoint_Loop_D1.80mm_Drill1.0mm_Beaded
TP12: MOSI; TestPoint_Loop_D1.80mm_Drill1.0mm_Beaded
TP13: SCK; TestPoint_Loop_D1.80mm_Drill1.0mm_Beaded
TP14: NSS; TestPoint_Loop_D1.80mm_Drill1.0mm_Beaded
TP15: ~{OE}; TestPoint_Loop_D1.80mm_Drill1.0mm_Beaded
U1: USBLC6-2SC6; SOT-23-6
U2: 74HC14; SOIC-14_3.9x8.7mm_P1.27mm
U3: 24C32; SO-8_3.9x4.9mm_P1.27mm
U4: STM32G441KB; LQFP-32_7x7mm_P0.8mm
Y1: 16MHz; Crystal_HC49-4H_Vertical

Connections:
+3.3V: C1.1, C2.1, C4.1, C10.1, C11.1, C12.1, C13.1, C14.2, C15.1, C16.1, D1.2 (A), D2.2 (A), J1.3, J5.1, R8.2, R9.2, R14.1, R15.1, SW2.2, TP4.1, U2.14 (VCC), U3.8 (VCC), U4.1 (VDD), U4.15 (VDDA), U4.17 (VDD); also elsewhere on the board
+15V: Q2.3 (D), TP10.1; also elsewhere on the board
/ADC_TEMP1: C6.1, R8.1, TH1.1, U4.8 (PA3)
/ADC_TEMP2: C9.1, R9.1, TH2.1, U4.13 (PB0)
/EXT_IN1: TP5.1, U2.4, U4.19 (PA9)
/EXT_IN2: TP6.1, U2.8, U4.18 (PA8)
/I2C1_SCL: J4.1, R13.2, R14.2, TP8.1, U4.25 (PA15)
/I2C1_SDA: J4.2, R12.2, R15.2, TP11.1, U4.30 (PB7)
/RESET: C5.1, J5.5, SW1.2, U4.4 (PG10-NRST)
/RLY_PWR: R5.1, U4.7 (PA2)
/RLY_SPI3_MOSI: TP12.1, U4.12 (PA7); also elsewhere on the board
/RLY_SPI3_NSS: TP14.1, U4.9 (PA4); also elsewhere on the board
/RLY_SPI3_SCK: TP13.1, U4.10 (PA5); also elsewhere on the board
/SWCLK: J5.2, U4.24 (PA14)
/SWDIO: J5.4, U4.23 (PA13)
/USB_D+: U1.1 (I/O1), U4.22 (PA12)
/USB_D-: U1.3 (I/O2), U4.21 (PA11)
/VBUS: J3.1 (VBUS), U1.5 (VBUS)
/resistor_decades/RES1_A: J6.4, J6.5; also elsewhere on the board
/resistor_decades/RES1_B: J6.1, J6.2; also elsewhere on the board
/~DISP_RESET: J4.3, TP7.1, U4.26 (PB3)
/~INT_UI: J4.4, TP9.1, U4.27 (PB4)
/~RLY_OE: TP15.1, U4.11 (PA6); also elsewhere on the board
GND: C1.2, C2.2, C3.2, C4.2, C5.2, C6.2, C7.2, C8.2, C9.2, C10.2, C11.2, C12.2, C13.2, C14.1, C15.2, C16.2, D1.1 (K), D2.1 (K), J1.2, J2.3, J3.4 (GND), J4.5, J4.6, J5.3, Q1.2 (S), R3.2, R4.2, R6.2, R10.2, SW1.1, TH1.2, TH2.2, TP1.1, TP2.1, U1.2 (GND), U2.7 (GND), U2.11, U2.13, U3.1 (A0), U3.2 (A1), U3.3 (A2), U3.4 (GND), U4.14 (VSSA), U4.16 (VSS), U4.32 (VSS); also elsewhere on the board
unnamed: D1.3 (K), R1.2, R3.1, U2.1
unnamed: D2.3 (K), R2.2, R4.1, U2.5
unnamed: C3.1, J1.1, Q2.2 (S), R7.1, TP3.1
unnamed: J2.1, R1.1
unnamed: J2.2, R2.1
unnamed: J3.3 (D+), U1.6 (I/O1)
unnamed: J3.2 (D-), U1.4 (I/O2)
unnamed: Q1.3 (D), Q2.1 (G), R7.2
unnamed: Q1.1 (G), R5.2, R6.1
unnamed: R10.1, R11.1, SW2.1
unnamed: U2.2, U2.3
unnamed: U2.6, U2.9
unnamed: R13.1, U3.6 (SCL)
unnamed: R12.1, U3.5 (SDA)
unnamed: R11.2, U4.31 (PB8-BOOT0)
unnamed: C7.1, U4.2 (PF0-OSC_IN), Y1.1
unnamed: C8.1, U4.3 (PF1-OSC_OUT), Y1.2

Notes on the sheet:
EEPROM
Power
Microcontroller STM32G
Mounting holes
USB connector
External inputs
Temperature measurement
Relay switching, resistor decade
SWD interface
UI board connector

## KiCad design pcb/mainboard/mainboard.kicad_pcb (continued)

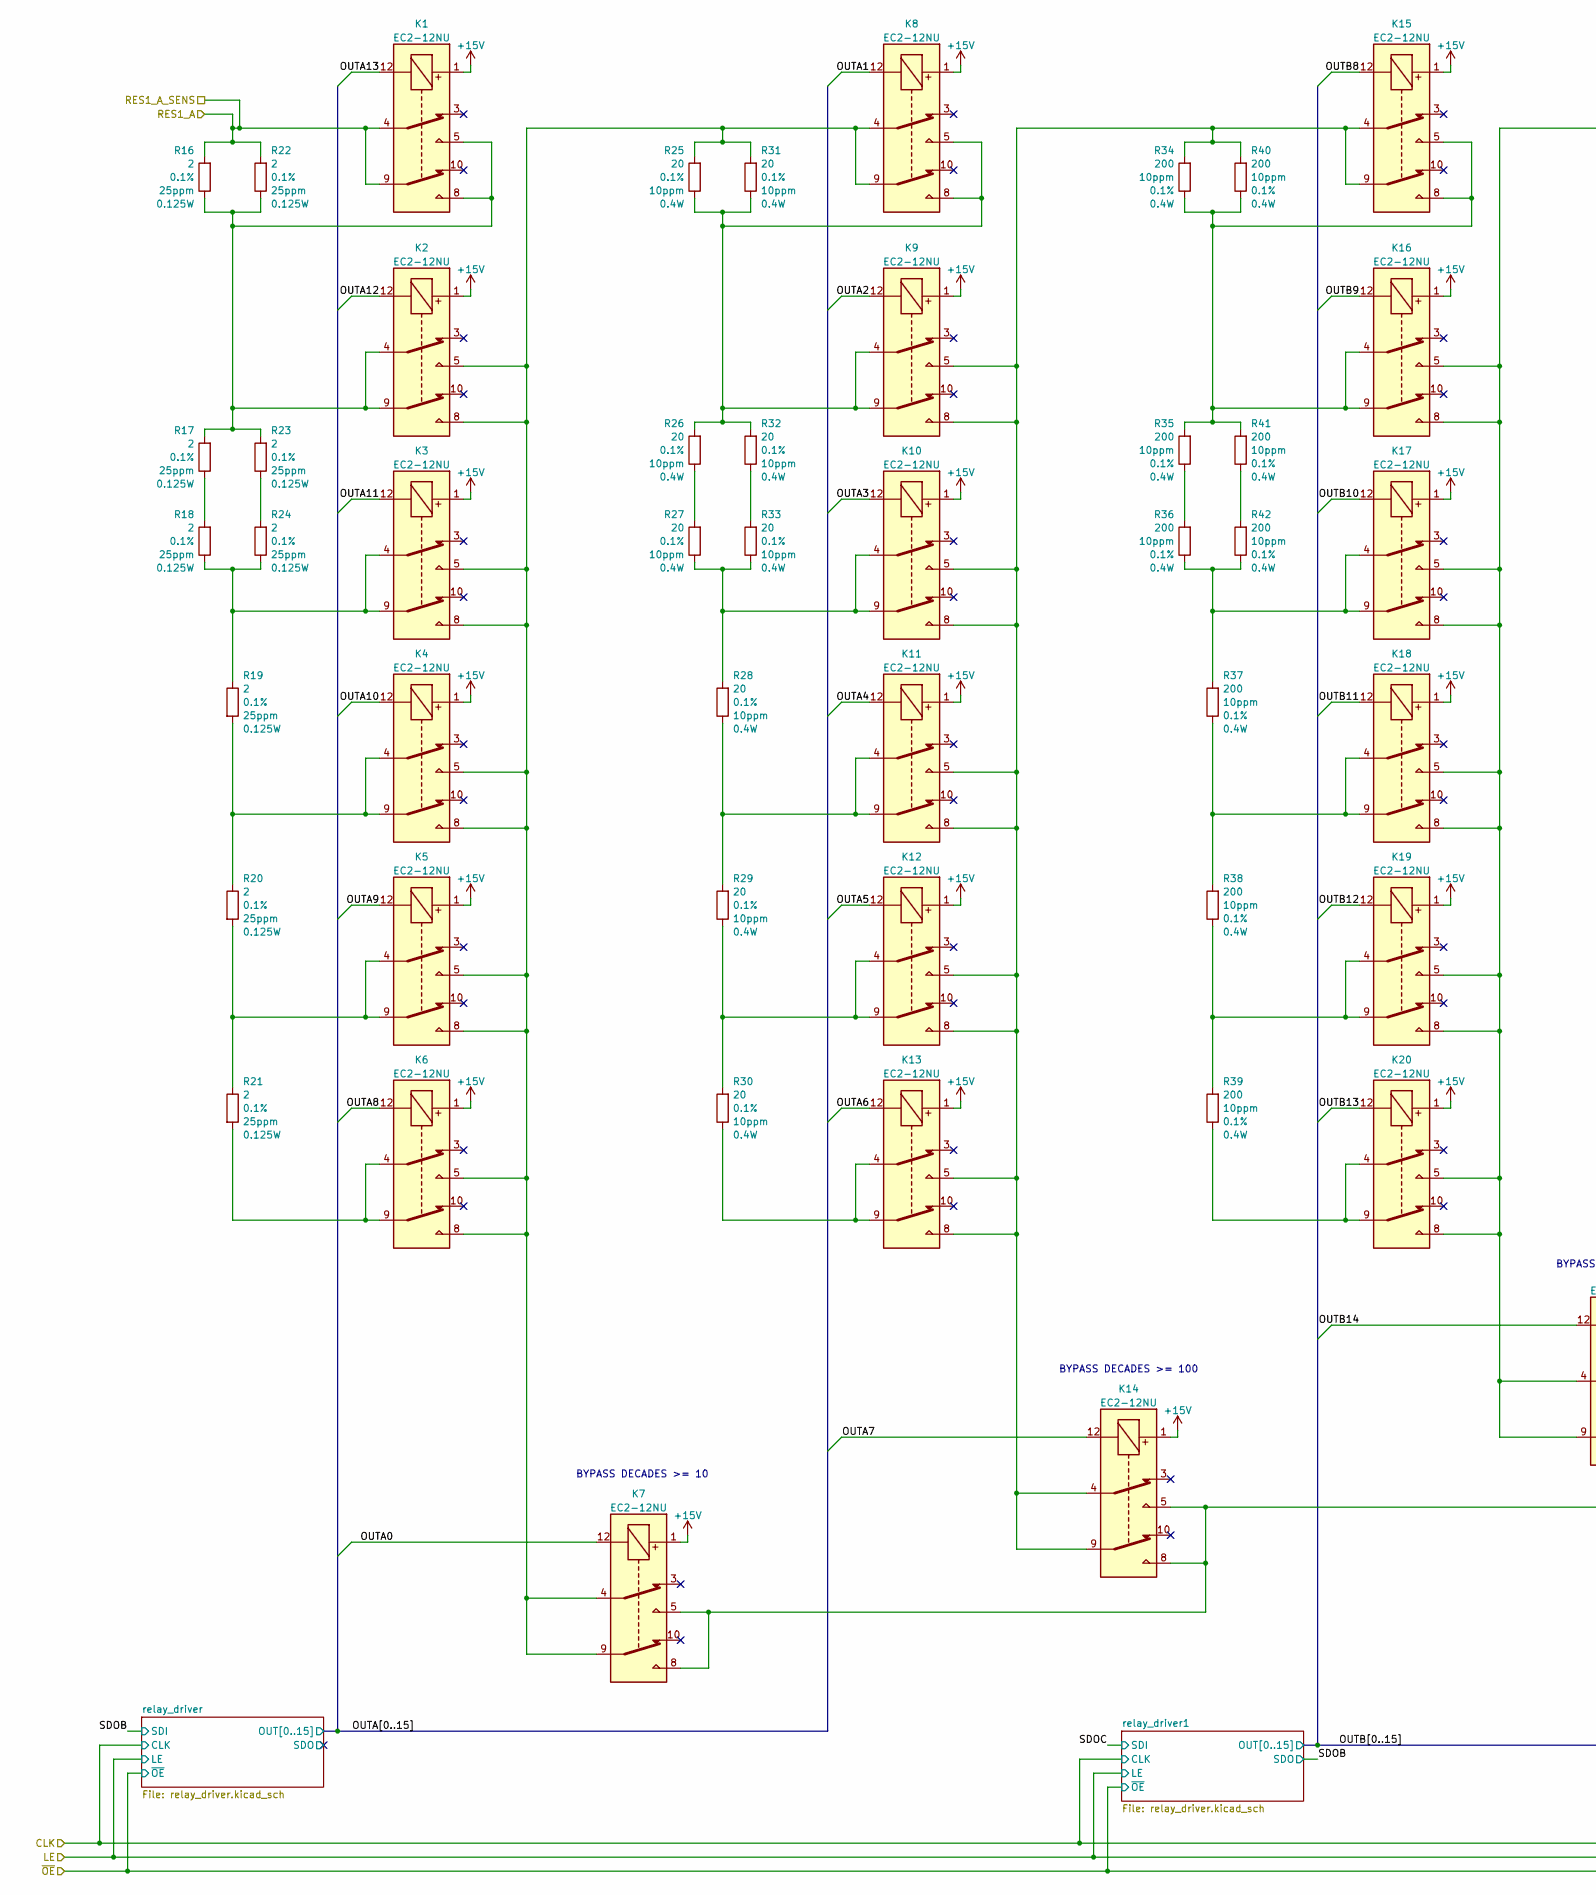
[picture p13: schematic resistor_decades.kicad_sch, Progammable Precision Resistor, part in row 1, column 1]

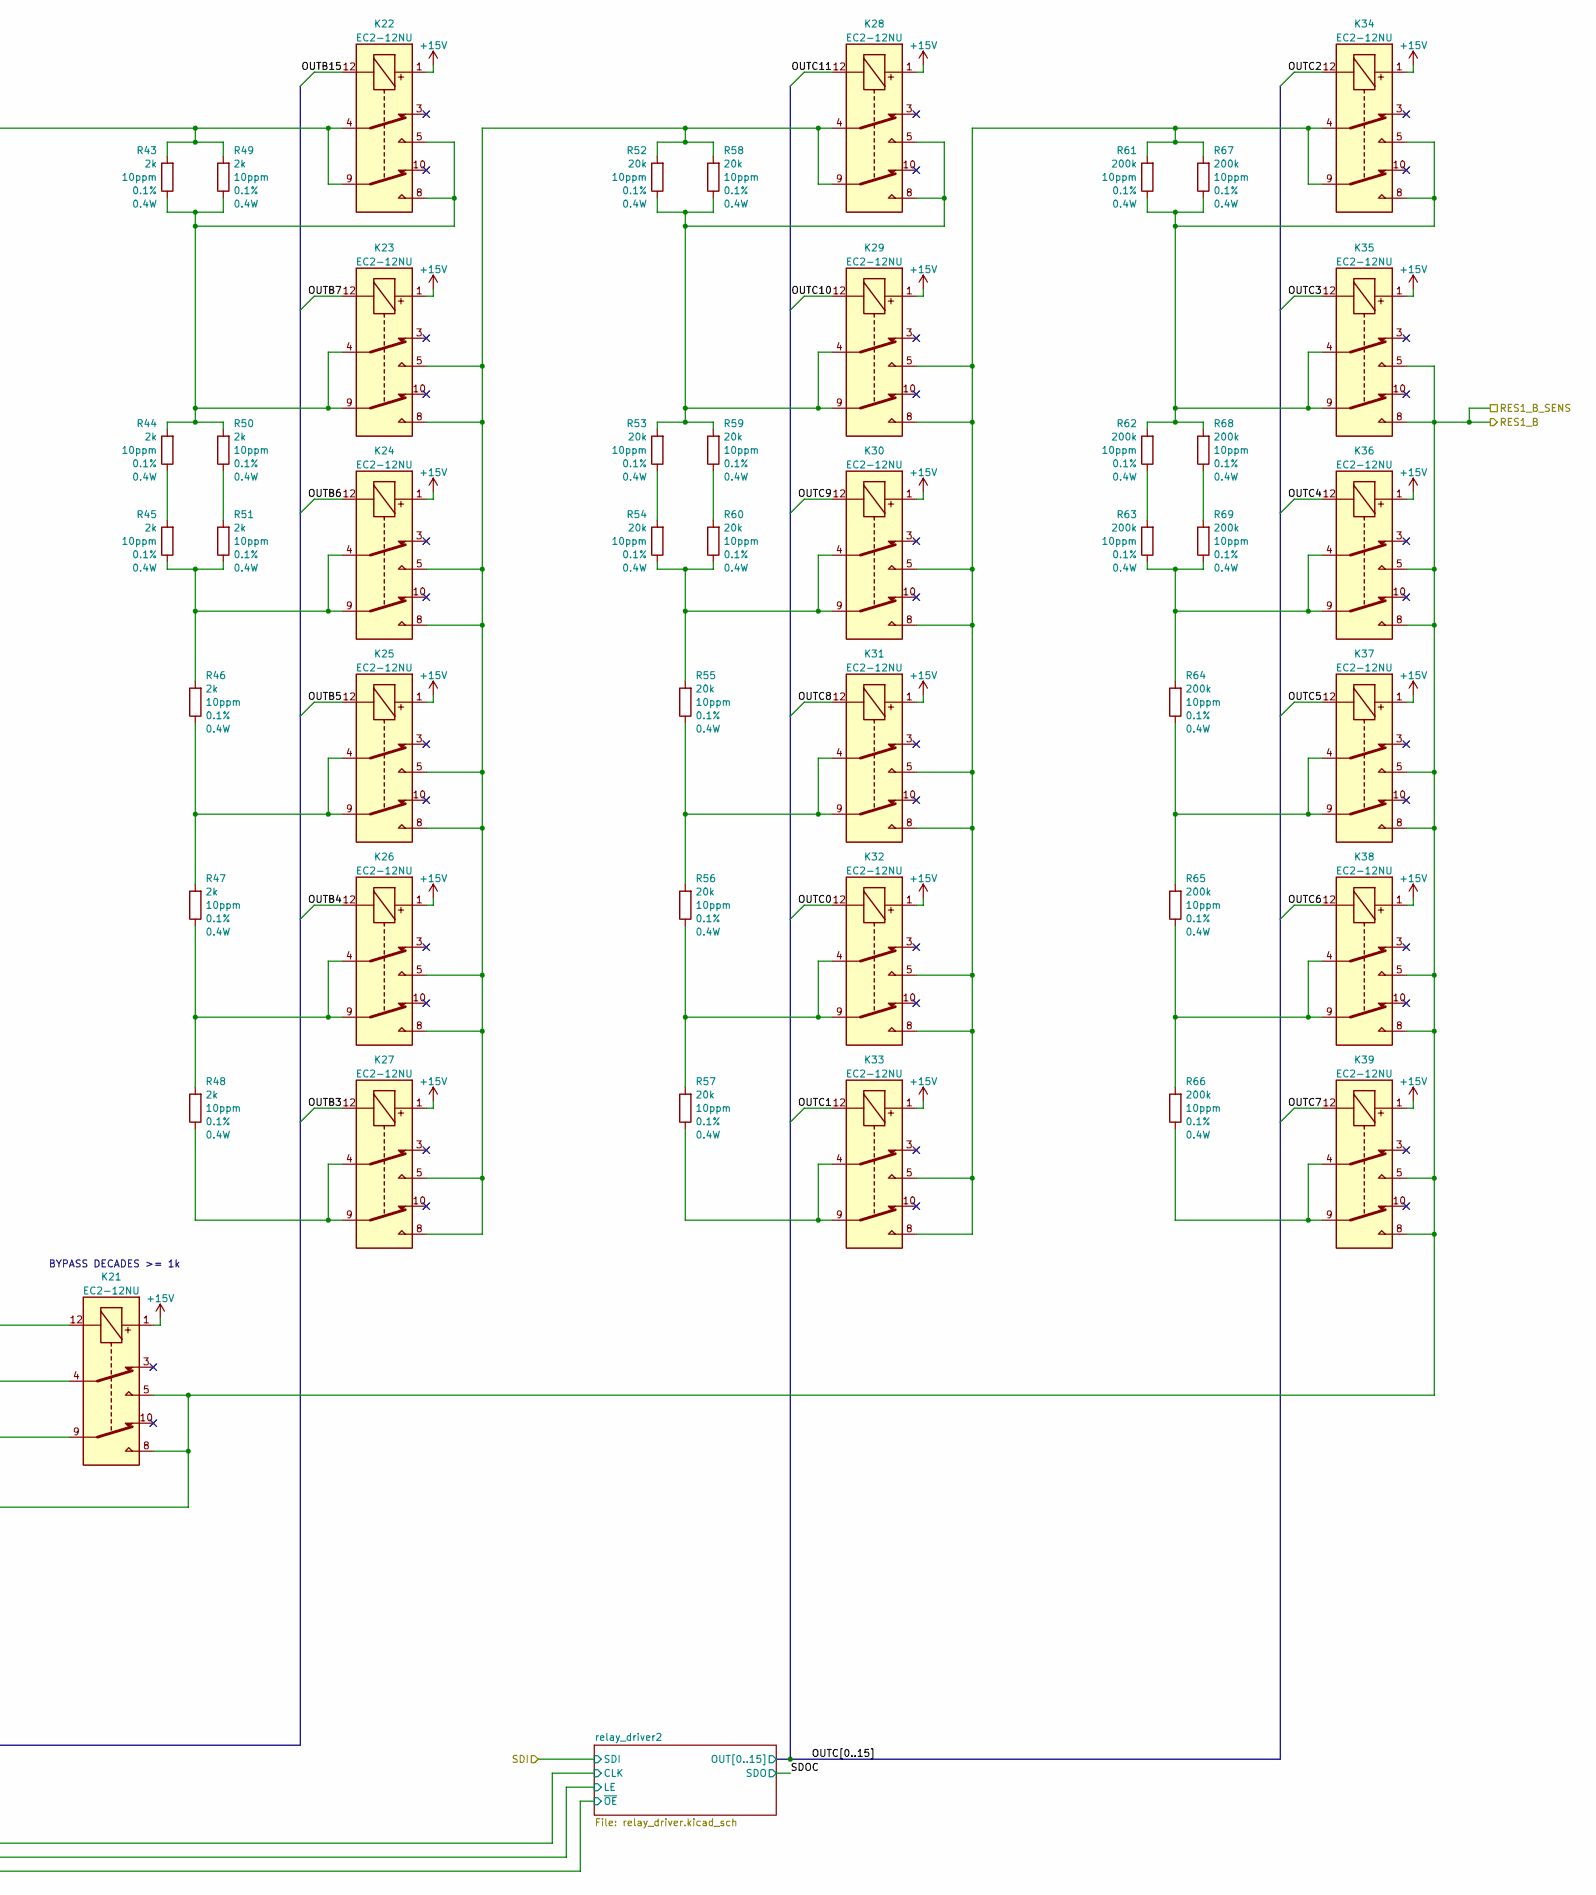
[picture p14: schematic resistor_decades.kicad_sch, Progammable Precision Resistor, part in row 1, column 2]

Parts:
K1, K2, K3, K4, K5, K6, K7, K8, K9, K10, K11, K12, K13, K14, K15, K16, K17, K18, K19, K20, K21, K22, K23, K24, K25, K26, K27, K28, K29, K30, K31, K32, K33, K34, K35, K36, K37, K38, K39: EC2-12NU; Relay_DPDT_Kemet_EC2
R16, R17, R18, R19, R20, R21, R22, R23, R24: 2; R_1206_3216Metric_Box; Tolerance 0.1%
R25, R26, R27, R28, R29, R30, R31, R32, R33: 20; R_1206_3216Metric_Box; Tolerance 0.1%
R34, R35, R36, R37, R38, R39, R40, R41, R42: 200; R_1206_3216Metric_Box; Tolerance 0.1%
R43, R44, R45, R46, R47, R48, R49, R50, R51: 2k; R_1206_3216Metric_Box; Tolerance 0.1%
R52, R53, R54, R55, R56, R57, R58, R59, R60: 20k; R_1206_3216Metric_Box; Tolerance 0.1%
R61, R62, R63, R64, R65, R66, R67, R68, R69: 200k; R_1206_3216Metric_Box; Tolerance 0.1%

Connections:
+15V: K1.1, K2.1, K3.1, K4.1, K5.1, K6.1, K7.1, K8.1, K9.1, K10.1, K11.1, K12.1, K13.1, K14.1, K15.1, K16.1, K17.1, K18.1, K19.1, K20.1, K21.1, K22.1, K23.1, K24.1, K25.1, K26.1, K27.1, K28.1, K29.1, K30.1, K31.1, K32.1, K33.1, K34.1, K35.1, K36.1, K37.1, K38.1, K39.1; also elsewhere on the board
/resistor_decades/OUTA0: K7.12; also elsewhere on the board
/resistor_decades/OUTA1: K8.12; also elsewhere on the board
/resistor_decades/OUTA2: K9.12; also elsewhere on the board
/resistor_decades/OUTA3: K10.12; also elsewhere on the board
/resistor_decades/OUTA4: K11.12; also elsewhere on the board
/resistor_decades/OUTA5: K12.12; also elsewhere on the board
/resistor_decades/OUTA6: K13.12; also elsewhere on the board
/resistor_decades/OUTA7: K14.12; also elsewhere on the board
/resistor_decades/OUTA8: K6.12; also elsewhere on the board
/resistor_decades/OUTA9: K5.12; also elsewhere on the board
/resistor_decades/OUTA10: K4.12; also elsewhere on the board
/resistor_decades/OUTA11: K3.12; also elsewhere on the board
/resistor_decades/OUTA12: K2.12; also elsewhere on the board
/resistor_decades/OUTA13: K1.12; also elsewhere on the board
/resistor_decades/OUTB3: K27.12; also elsewhere on the board
/resistor_decades/OUTB4: K26.12; also elsewhere on the board
/resistor_decades/OUTB5: K25.12; also elsewhere on the board
/resistor_decades/OUTB6: K24.12; also elsewhere on the board
/resistor_decades/OUTB7: K23.12; also elsewhere on the board
/resistor_decades/OUTB8: K15.12; also elsewhere on the board
/resistor_decades/OUTB9: K16.12; also elsewhere on the board
/resistor_decades/OUTB10: K17.12; also elsewhere on the board
/resistor_decades/OUTB11: K18.12; also elsewhere on the board
/resistor_decades/OUTB12: K19.12; also elsewhere on the board
/resistor_decades/OUTB13: K20.12; also elsewhere on the board
/resistor_decades/OUTB14: K21.12; also elsewhere on the board
/resistor_decades/OUTB15: K22.12; also elsewhere on the board
/resistor_decades/OUTC0: K32.12; also elsewhere on the board
/resistor_decades/OUTC1: K33.12; also elsewhere on the board
/resistor_decades/OUTC2: K34.12; also elsewhere on the board
/resistor_decades/OUTC3: K35.12; also elsewhere on the board
/resistor_decades/OUTC4: K36.12; also elsewhere on the board
/resistor_decades/OUTC5: K37.12; also elsewhere on the board
/resistor_decades/OUTC6: K38.12; also elsewhere on the board
/resistor_decades/OUTC7: K39.12; also elsewhere on the board
/resistor_decades/OUTC8: K31.12; also elsewhere on the board
/resistor_decades/OUTC9: K30.12; also elsewhere on the board
/resistor_decades/OUTC10: K29.12; also elsewhere on the board
/resistor_decades/OUTC11: K28.12; also elsewhere on the board
/resistor_decades/RES1_A: K1.4, K1.9, R16.2, R22.2; also elsewhere on the board
/resistor_decades/RES1_B: K7.5, K7.8, K14.5, K14.8, K21.5, K21.8, K35.5, K35.8, K36.5, K36.8, K37.5, K37.8, K38.5, K38.8, K39.5, K39.8; also elsewhere on the board
unnamed: K1.5, K1.8, K2.4, K2.9, R16.1, R17.2, R22.1, R23.2
unnamed: K2.5, K2.8, K3.5, K3.8, K4.5, K4.8, K5.5, K5.8, K6.5, K6.8, K7.4, K7.9, K8.4, K8.9, R25.2, R31.2
unnamed: K3.4, K3.9, R18.1, R19.1, R24.1
unnamed: K4.4, K4.9, R19.2, R20.1
unnamed: K5.4, K5.9, R20.2, R21.1
unnamed: K6.4, K6.9, R21.2
unnamed: K8.5, K8.8, K9.4, K9.9, R25.1, R26.2, R31.1, R32.2
unnamed: K10.4, K10.9, R27.1, R28.2, R33.1
unnamed: K9.5, K9.8, K10.5, K10.8, K11.5, K11.8, K12.5, K12.8, K13.5, K13.8, K14.4, K14.9, K15.4, K15.9, R34.2, R40.2
unnamed: K11.4, K11.9, R28.1, R29.2
unnamed: K12.4, K12.9, R29.1, R30.2
unnamed: K13.4, K13.9, R30.1
unnamed: K15.5, K15.8, K16.4, K16.9, R34.1, R35.2, R40.1, R41.2
unnamed: K16.5, K16.8, K17.5, K17.8, K18.5, K18.8, K19.5, K19.8, K20.5, K20.8, K21.4, K21.9, K22.4, K22.9, R43.2, R49.2
unnamed: K17.4, K17.9, R36.1, R37.2, R42.1
unnamed: K18.4, K18.9, R37.1, R38.2
unnamed: K19.4, K19.9, R38.1, R39.2
unnamed: K20.4, K20.9, R39.1
unnamed: K22.5, K22.8, K23.4, K23.9, R43.1, R44.2, R49.1, R50.2
unnamed: K23.5, K23.8, K24.5, K24.8, K25.5, K25.8, K26.5, K26.8, K27.5, K27.8, K28.4, K28.9, R52.2, R58.2
unnamed: K24.4, K24.9, R45.1, R46.2, R51.1
unnamed: K25.4, K25.9, R46.1, R47.2
unnamed: K26.4, K26.9, R47.1, R48.2
unnamed: K27.4, K27.9, R48.1
unnamed: K28.5, K28.8, K29.4, K29.9, R52.1, R53.2, R58.1, R59.2
unnamed: K29.5, K29.8, K30.5, K30.8, K31.5, K31.8, K32.5, K32.8, K33.5, K33.8, K34.4, K34.9, R61.2, R67.2
unnamed: K30.4, K30.9, R54.1, R55.2, R60.1
unnamed: K31.4, K31.9, R55.1, R56.2
unnamed: K32.4, K32.9, R56.1, R57.2
unnamed: K33.4, K33.9, R57.1
unnamed: K34.5, K34.8, K35.4, K35.9, R61.1, R62.2, R67.1, R68.2
unnamed: K36.4, K36.9, R63.1, R64.2, R69.1
unnamed: K37.4, K37.9, R64.1, R65.2
unnamed: K38.4, K38.9, R65.1, R66.2
unnamed: K39.4, K39.9, R66.1
unnamed: R17.1, R18.2
unnamed: R23.1, R24.2
unnamed: R26.1, R27.2
unnamed: R32.1, R33.2
unnamed: R35.1, R36.2
unnamed: R41.1, R42.2
unnamed: R44.1, R45.2
unnamed: R50.1, R51.2
unnamed: R53.1, R54.2
unnamed: R59.1, R60.2
unnamed: R62.1, R63.2
unnamed: R68.1, R69.2

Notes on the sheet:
BYPASS DECADES >= 1k
BYPASS DECADES >= 100
BYPASS DECADES >= 10

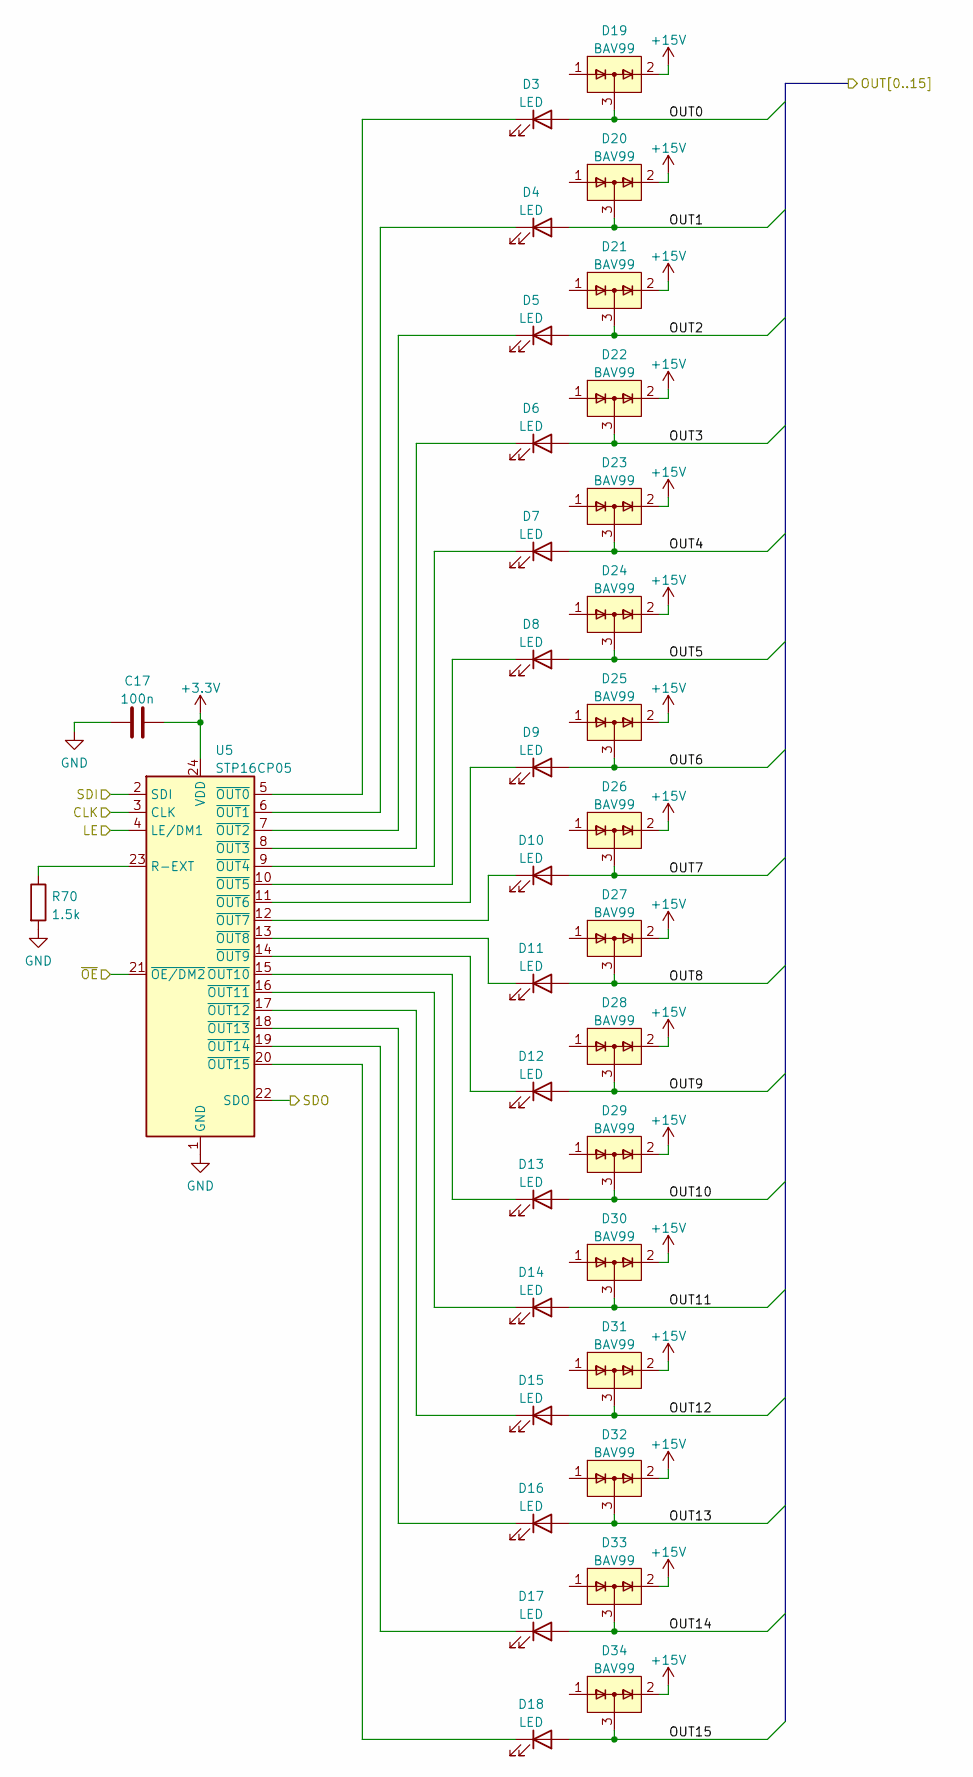
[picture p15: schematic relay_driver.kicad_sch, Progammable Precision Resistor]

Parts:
C17: 100n; C_0805_2012Metric_Box
D3, D4, D5, D6, D7, D8, D9, D10, D11, D12, D13, D14, D15, D16, D17, D18: LED; LED_0805_2012Metric
D19, D20, D21, D22, D23, D24, D25, D26, D27, D28, D29, D30, D31, D32, D33, D34: BAV99; SOT-23
R70: 1.5k; R_0805_2012Metric_Box
U5: STP16CP05; TSSOP-24_4.4x7.8mm_P0.65mm

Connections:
+3.3V: C17.2, U5.24 (VDD); also elsewhere on the board
+15V: D19.2 (A), D20.2 (A), D21.2 (A), D22.2 (A), D23.2 (A), D24.2 (A), D25.2 (A), D26.2 (A), D27.2 (A), D28.2 (A), D29.2 (A), D30.2 (A), D31.2 (A), D32.2 (A); also elsewhere on the board
/RLY_SPI3_NSS: U5.4 (LE/DM1); also elsewhere on the board
/RLY_SPI3_SCK: U5.3 (CLK); also elsewhere on the board
/resistor_decades/OUTA0: D3.2 (A), D19.3 (K); also elsewhere on the board
/resistor_decades/OUTA1: D4.2 (A), D20.3 (K); also elsewhere on the board
/resistor_decades/OUTA2: D5.2 (A), D21.3 (K); also elsewhere on the board
/resistor_decades/OUTA3: D6.2 (A), D22.3 (K); also elsewhere on the board
/resistor_decades/OUTA4: D7.2 (A), D23.3 (K); also elsewhere on the board
/resistor_decades/OUTA5: D8.2 (A), D24.3 (K); also elsewhere on the board
/resistor_decades/OUTA6: D9.2 (A), D25.3 (K); also elsewhere on the board
/resistor_decades/OUTA7: D10.2 (A), D26.3 (K); also elsewhere on the board
/resistor_decades/OUTA8: D11.2 (A), D27.3 (K); also elsewhere on the board
/resistor_decades/OUTA9: D12.2 (A), D28.3 (K); also elsewhere on the board
/resistor_decades/OUTA10: D13.2 (A), D29.3 (K); also elsewhere on the board
/resistor_decades/OUTA11: D14.2 (A), D30.3 (K); also elsewhere on the board
/resistor_decades/OUTA12: D15.2 (A), D31.3 (K); also elsewhere on the board
/resistor_decades/OUTA13: D16.2 (A), D32.3 (K); also elsewhere on the board
/resistor_decades/SDOB: U5.2 (SDI); also elsewhere on the board
/resistor_decades/relay_driver/SDO: U5.22 (SDO)
/~RLY_OE: U5.21 (~OE/DM2); also elsewhere on the board
GND: C17.1, R70.2, U5.1 (GND); also elsewhere on the board
unnamed: D3.1 (K), U5.5 (~OUT0)
unnamed: D4.1 (K), U5.6 (~OUT1)
unnamed: D5.1 (K), U5.7 (~OUT2)
unnamed: D6.1 (K), U5.8 (~OUT3)
unnamed: D7.1 (K), U5.9 (~OUT4)
unnamed: D8.1 (K), U5.10 (~OUT5)
unnamed: D9.1 (K), U5.11 (~OUT6)
unnamed: D10.1 (K), U5.12 (~OUT7)
unnamed: D11.1 (K), U5.13 (~OUT8)
unnamed: D12.1 (K), U5.14 (~OUT9)
unnamed: D13.1 (K), U5.15 (~OUT10)
unnamed: D14.1 (K), U5.16 (~OUT11)
unnamed: D15.1 (K), U5.17 (~OUT12)
unnamed: D16.1 (K), U5.18 (~OUT13)
unnamed: R70.1, U5.23 (R-EXT)

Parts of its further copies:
C18, C19: 100n; C_0805_2012Metric_Box
D38, D39, D40, D41, D42, D43, D44, D45, D46, D47, D48, D49, D50, D67, D68, D69, D70, D71, D72, D73, D74, D75, D76, D77, D78: LED; LED_0805_2012Metric
D54, D55, D56, D57, D58, D59, D60, D61, D62, D63, D64, D65, D66, D83, D84, D85, D86, D87, D88, D89, D90, D91, D92, D93, D94: BAV99; SOT-23
R71, R72: 1.5k; R_0805_2012Metric_Box
U6, U7: STP16CP05; TSSOP-24_4.4x7.8mm_P0.65mm

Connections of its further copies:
+3.3V: C18.2, C19.2, U6.24 (VDD), U7.24 (VDD); also elsewhere on the board
+15V: D54.2 (A), D55.2 (A), D56.2 (A), D57.2 (A), D58.2 (A), D59.2 (A), D60.2 (A), D61.2 (A), D62.2 (A), D63.2 (A), D64.2 (A), D65.2 (A), D66.2 (A), D83.2 (A), D84.2 (A), D85.2 (A), D86.2 (A), D87.2 (A), D88.2 (A), D89.2 (A), D90.2 (A), D91.2 (A), D92.2 (A), D93.2 (A), D94.2 (A); also elsewhere on the board
/RLY_SPI3_MOSI: U7.2 (SDI); also elsewhere on the board
/RLY_SPI3_NSS: U6.4 (LE/DM1), U7.4 (LE/DM1); also elsewhere on the board
/RLY_SPI3_SCK: U6.3 (CLK), U7.3 (CLK); also elsewhere on the board
/resistor_decades/OUTB3: D38.2 (A), D54.3 (K); also elsewhere on the board
/resistor_decades/OUTB4: D39.2 (A), D55.3 (K); also elsewhere on the board
/resistor_decades/OUTB5: D40.2 (A), D56.3 (K); also elsewhere on the board
/resistor_decades/OUTB6: D41.2 (A), D57.3 (K); also elsewhere on the board
/resistor_decades/OUTB7: D42.2 (A), D58.3 (K); also elsewhere on the board
/resistor_decades/OUTB8: D43.2 (A), D59.3 (K); also elsewhere on the board
/resistor_decades/OUTB9: D44.2 (A), D60.3 (K); also elsewhere on the board
/resistor_decades/OUTB10: D45.2 (A), D61.3 (K); also elsewhere on the board
/resistor_decades/OUTB11: D46.2 (A), D62.3 (K); also elsewhere on the board
/resistor_decades/OUTB12: D47.2 (A), D63.3 (K); also elsewhere on the board
/resistor_decades/OUTB13: D48.2 (A), D64.3 (K); also elsewhere on the board
/resistor_decades/OUTB14: D49.2 (A), D65.3 (K); also elsewhere on the board
/resistor_decades/OUTB15: D50.2 (A), D66.3 (K); also elsewhere on the board
/resistor_decades/OUTC0: D67.2 (A), D83.3 (K); also elsewhere on the board
/resistor_decades/OUTC1: D68.2 (A), D84.3 (K); also elsewhere on the board
/resistor_decades/OUTC2: D69.2 (A), D85.3 (K); also elsewhere on the board
/resistor_decades/OUTC3: D70.2 (A), D86.3 (K); also elsewhere on the board
/resistor_decades/OUTC4: D71.2 (A), D87.3 (K); also elsewhere on the board
/resistor_decades/OUTC5: D72.2 (A), D88.3 (K); also elsewhere on the board
/resistor_decades/OUTC6: D73.2 (A), D89.3 (K); also elsewhere on the board
/resistor_decades/OUTC7: D74.2 (A), D90.3 (K); also elsewhere on the board
/resistor_decades/OUTC8: D75.2 (A), D91.3 (K); also elsewhere on the board
/resistor_decades/OUTC9: D76.2 (A), D92.3 (K); also elsewhere on the board
/resistor_decades/OUTC10: D77.2 (A), D93.3 (K); also elsewhere on the board
/resistor_decades/OUTC11: D78.2 (A), D94.3 (K); also elsewhere on the board
/resistor_decades/SDOB: U6.22 (SDO); also elsewhere on the board
/resistor_decades/SDOC: U6.2 (SDI), U7.22 (SDO)
/~RLY_OE: U6.21 (~OE/DM2), U7.21 (~OE/DM2); also elsewhere on the board
GND: C18.1, C19.1, R71.2, R72.2, U6.1 (GND), U7.1 (GND); also elsewhere on the board
unnamed: D38.1 (K), U6.8 (~OUT3)
unnamed: D39.1 (K), U6.9 (~OUT4)
unnamed: D40.1 (K), U6.10 (~OUT5)
unnamed: D41.1 (K), U6.11 (~OUT6)
unnamed: D42.1 (K), U6.12 (~OUT7)
unnamed: D43.1 (K), U6.13 (~OUT8)
unnamed: D44.1 (K), U6.14 (~OUT9)
unnamed: D45.1 (K), U6.15 (~OUT10)
unnamed: D46.1 (K), U6.16 (~OUT11)
unnamed: D47.1 (K), U6.17 (~OUT12)
unnamed: D48.1 (K), U6.18 (~OUT13)
unnamed: D67.1 (K), U7.5 (~OUT0)
unnamed: D68.1 (K), U7.6 (~OUT1)
unnamed: D69.1 (K), U7.7 (~OUT2)
unnamed: D70.1 (K), U7.8 (~OUT3)
unnamed: D71.1 (K), U7.9 (~OUT4)
unnamed: D72.1 (K), U7.10 (~OUT5)
unnamed: D73.1 (K), U7.11 (~OUT6)
unnamed: D74.1 (K), U7.12 (~OUT7)
unnamed: D75.1 (K), U7.13 (~OUT8)
unnamed: D76.1 (K), U7.14 (~OUT9)
unnamed: D77.1 (K), U7.15 (~OUT10)
unnamed: D78.1 (K), U7.16 (~OUT11)
unnamed: R71.1, U6.23 (R-EXT)
unnamed: R72.1, U7.23 (R-EXT)

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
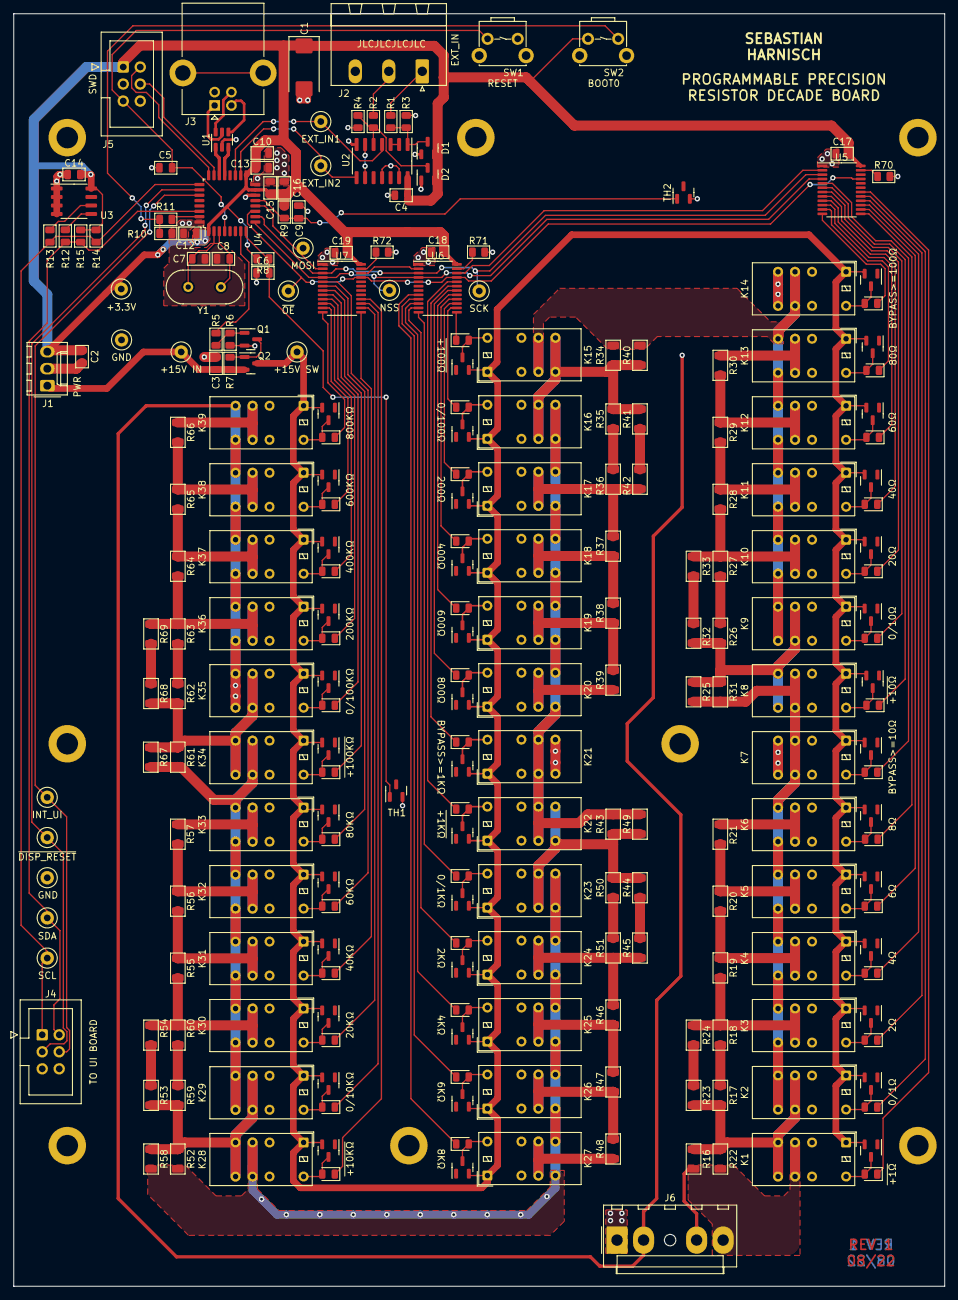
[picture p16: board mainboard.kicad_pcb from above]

Board: 2 copper layers, 139.0 x 190.0 mm, 253 parts (1 on the bottom side), 171 nets.

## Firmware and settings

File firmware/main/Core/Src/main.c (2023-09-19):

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
/* Includes ------------------------------------------------------------------*/
#include "main.h"
#include "cmsis_os.h"
#include "usb_device.h"

/* USER CODE BEGIN Includes */
#include "base.h"
/* USER CODE END Includes */

typedef StaticTask_t osStaticThreadDef_t;
typedef StaticQueue_t osStaticMessageQDef_t;
typedef StaticTimer_t osStaticTimerDef_t;
typedef StaticSemaphore_t osStaticMutexDef_t;
ADC_HandleTypeDef hadc1;
DMA_HandleTypeDef hdma_adc1;

CRC_HandleTypeDef hcrc;

I2C_HandleTypeDef hi2c1;

SPI_HandleTypeDef hspi1;

TIM_HandleTypeDef htim7;

/* Definitions for scpiTask */
osThreadId_t scpiTaskHandle;
uint32_t scpiTaskBuffer[ 512 ];
osStaticThreadDef_t scpiTaskControlBlock;
const osThreadAttr_t scpiTask_attributes = {
  .name = "scpiTask",
  .stack_mem = &scpiTaskBuffer[0],
  .stack_size = sizeof(scpiTaskBuffer),
  .cb_mem = &scpiTaskControlBlock,
  .cb_size = sizeof(scpiTaskControlBlock),
  .priority = (osPriority_t) osPriorityAboveNormal,
};
/* Definitions for uiTask */
osThreadId_t uiTaskHandle;
uint32_t uiTaskBuffer[ 512 ];
osStaticThreadDef_t uiTaskControlBlock;
const osThreadAttr_t uiTask_attributes = {
  .name = "uiTask",
  .stack_mem = &uiTaskBuffer[0],
  .stack_size = sizeof(uiTaskBuffer),
  .cb_mem = &uiTaskControlBlock,
  .cb_size = sizeof(uiTaskControlBlock),
  .priority = (osPriority_t) osPriorityNormal,
};
/* Definitions for keycodeQueue */
osMessageQueueId_t keycodeQueueHandle;
uint8_t keycodeQueueBuffer[ 16 * sizeof( uint8_t ) ];
osStaticMessageQDef_t keycodeQueueControlBlock;
const osMessageQueueAttr_t keycodeQueue_attributes = {
  .name = "keycodeQueue",
  .cb_mem = &keycodeQueueControlBlock,
  .cb_size = sizeof(keycodeQueueControlBlock),
  .mq_mem = &keycodeQueueBuffer,
  .mq_size = sizeof(keycodeQueueBuffer)
};
/* Definitions for encoderQueue */
osMessageQueueId_t encoderQueueHandle;
uint8_t encoderQueueBuffer[ 16 * sizeof( int16_t ) ];
osStaticMessageQDef_t encoderQueueControlBlock;
const osMessageQueueAttr_t encoderQueue_attributes = {
  .name = "encoderQueue",
  .cb_mem = &encoderQueueControlBlock,
  .cb_size = sizeof(encoderQueueControlBlock),
  .mq_mem = &encoderQueueBuffer,
  .mq_size = sizeof(encoderQueueBuffer)
};
/* Definitions for timer10ms */
osTimerId_t timer10msHandle;
osStaticTimerDef_t timer10msControlBlock;
const osTimerAttr_t timer10ms_attributes = {
  .name = "timer10ms",
  .cb_mem = &timer10msControlBlock,
  .cb_size = sizeof(timer10msControlBlock),
};
/* Definitions for i2cMutex */
osMutexId_t i2cMutexHandle;
osStaticMutexDef_t i2cMutexControlBlock;
const osMutexAttr_t i2cMutex_attributes = {
  .name = "i2cMutex",
  .cb_mem = &i2cMutexControlBlock,
  .cb_size = sizeof(i2cMutexControlBlock),
};
void SystemClock_Config(void);
static void MX_GPIO_Init(void);
static void MX_DMA_Init(void);
static void MX_I2C1_Init(void);
static void MX_SPI1_Init(void);
static void MX_ADC1_Init(void);
static void MX_CRC_Init(void);
static void MX_TIM7_Init(void);
void BASE_StartScpiTask(void *argument);
void BASE_StartUiTask(void *argument);
void BASE_TimerTick_10ms(void *argument);

/**
  * @brief  The application entry point.
  * @retval int
  */
int main(void)
{
  /* MCU Configuration--------------------------------------------------------*/

  /* Reset of all peripherals, Initializes the Flash interface and the Systick. */
  HAL_Init();

  /* Configure the system clock */
  SystemClock_Config();

  /* Initialize all configured peripherals */
  MX_GPIO_Init();
  MX_DMA_Init();
  MX_I2C1_Init();
  MX_SPI1_Init();
  MX_ADC1_Init();
  MX_USB_Device_Init();
  MX_CRC_Init();
  MX_TIM7_Init();
  /* Init scheduler */
  osKernelInitialize();
  /* Create the mutex(es) */
  /* creation of i2cMutex */
  i2cMutexHandle = osMutexNew(&i2cMutex_attributes);

  /* USER CODE BEGIN RTOS_MUTEX */
  /* add mutexes, ... */
  /* USER CODE END RTOS_MUTEX */

  /* USER CODE BEGIN RTOS_SEMAPHORES */
  /* add semaphores, ... */
  /* USER CODE END RTOS_SEMAPHORES */

  /* Create the timer(s) */
  /* creation of timer10ms */
  timer10msHandle = osTimerNew(BASE_TimerTick_10ms, osTimerPeriodic, NULL, &timer10ms_attributes);

  /* USER CODE BEGIN RTOS_TIMERS */
  /* start timers, add new ones, ... */

  if (osTimerStart(timer10msHandle, 10) != osOK)
  {
	  // TODO: Add error handling
  }

  /* USER CODE END RTOS_TIMERS */

  /* Create the queue(s) */
  /* creation of keycodeQueue */
  keycodeQueueHandle = osMessageQueueNew (16, sizeof(uint8_t), &keycodeQueue_attributes);

  /* creation of encoderQueue */
  encoderQueueHandle = osMessageQueueNew (16, sizeof(int16_t), &encoderQueue_attributes);

  /* USER CODE BEGIN RTOS_QUEUES */
  /* add queues, ... */
  /* USER CODE END RTOS_QUEUES */

  /* Create the thread(s) */
  /* creation of scpiTask */
  scpiTaskHandle = osThreadNew(BASE_StartScpiTask, NULL, &scpiTask_attributes);

  /* creation of uiTask */
  uiTaskHandle = osThreadNew(BASE_StartUiTask, NULL, &uiTask_attributes);

  /* USER CODE BEGIN RTOS_THREADS */
  /* add threads, ... */
  /* USER CODE END RTOS_THREADS */

  /* USER CODE BEGIN RTOS_EVENTS */
  /* add events, ... */
  BASE_Init();
  /* USER CODE END RTOS_EVENTS */

  /* Start scheduler */
  osKernelStart();

  /* We should never get here as control is now taken by the scheduler */
  /* Infinite loop */
  /* USER CODE BEGIN WHILE */
  while (1)
  {
    /* USER CODE END WHILE */

    /* USER CODE BEGIN 3 */
  }
  /* USER CODE END 3 */
}

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
/* USER CODE BEGIN Header_BASE_StartScpiTask */
/**
  * @brief  Function implementing the scpiTask thread.
  * @param  argument: Not used
  * @retval None
  */
/* USER CODE END Header_BASE_StartScpiTask */
__weak void BASE_StartScpiTask(void *argument)
{
  /* USER CODE BEGIN 5 */
  /* Infinite loop */
  for(;;)
  {
    osDelay(1);
  }
  /* USER CODE END 5 */
}

/* USER CODE BEGIN Header_BASE_StartUiTask */
/**
* @brief Function implementing the uiTask thread.
* @param argument: Not used
* @retval None
*/
/* USER CODE END Header_BASE_StartUiTask */
__weak void BASE_StartUiTask(void *argument)
{
  /* USER CODE BEGIN BASE_StartUiTask */
  /* Infinite loop */
  for(;;)
  {
    osDelay(1);
  }
  /* USER CODE END BASE_StartUiTask */
}

/* BASE_TimerTick_10ms function */
__weak void BASE_TimerTick_10ms(void *argument)
{
}

/**
  * @brief  Period elapsed callback in non blocking mode
  * @note   This function is called  when TIM6 interrupt took place, inside
  * HAL_TIM_IRQHandler(). It makes a direct call to HAL_IncTick() to increment
  * a global variable "uwTick" used as application time base.
  * @param  htim : TIM handle
  * @retval None
  */
void HAL_TIM_PeriodElapsedCallback(TIM_HandleTypeDef *htim)
{
  /* USER CODE BEGIN Callback 0 */
	if (htim->Instance == TIM7)
	{
		BASE_AppTick();
	}
  /* USER CODE END Callback 0 */
  if (htim->Instance == TIM6) {
    HAL_IncTick();
  }
}

/**
  * @brief  This function is executed in case of error occurrence.
  * @retval None
  */
void Error_Handler(void)
{
  /* USER CODE BEGIN Error_Handler_Debug */
  /* User can add his own implementation to report the HAL error return state */
  __disable_irq();
  while (1)
  {
  }
  /* USER CODE END Error_Handler_Debug */
}

#ifdef  USE_FULL_ASSERT
/**
  * @brief  Reports the name of the source file and the source line number
  *         where the assert_param error has occurred.
  * @param  file: pointer to the source file name
  * @param  line: assert_param error line source number
  * @retval None
  */
void assert_failed(uint8_t *file, uint32_t line)
{
  /* USER CODE BEGIN 6 */
  /* User can add his own implementation to report the file name and line number,
     ex: printf("Wrong parameters value: file %s on line %d\r\n", file, line) */
  /* USER CODE END 6 */
}
#endif /* USE_FULL_ASSERT */

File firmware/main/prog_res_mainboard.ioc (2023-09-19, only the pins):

Mcu.UserName=STM32G441KBTx
PA11.Signal=USB_DM
PA12.Signal=USB_DP
PA13.Signal=SYS_JTMS-SWDIO
PA14.Signal=SYS_JTCK-SWCLK
PA15.Signal=I2C1_SCL
PA2.GPIO_Label=RLY_PWR
PA2.Signal=GPIO_Output
PA3.GPIO_Label=ADC1_IN4_TEMP1
PA3.Signal=ADC1_IN4
PA4.GPIO_Label=RLY_LE
PA4.Signal=GPIO_Output
PA5.GPIO_Label=RLY_SPI1_SCK
PA5.Signal=SPI1_SCK
PA6.GPIO_Label=RLY_OE
PA6.Signal=GPIO_Output
PA7.GPIO_Label=RLY_SPI1_MOSI
PA7.Signal=SPI1_MOSI
PA8.GPIO_Label=GPIO_EXT_IN2
PA8.Signal=GPIO_Input
PA9.GPIO_Label=GPIO_EXT_IN1
PA9.Signal=GPIO_Input
PB0.GPIO_Label=ADC1_IN_15_TEMP2
PB0.Signal=ADC1_IN15
PB3.GPIO_Label=NC
PB3.Signal=GPIO_Input
PB4.GPIO_Label=INT_UI
PB4.Signal=GPIO_Input
PB7.Signal=I2C1_SDA
PF0-OSC_IN.Signal=RCC_OSC_IN
PF1-OSC_OUT.Signal=RCC_OSC_OUT

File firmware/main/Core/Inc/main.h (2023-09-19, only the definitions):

#define RLY_PWR_Pin GPIO_PIN_2
#define RLY_PWR_GPIO_Port GPIOA
#define ADC1_IN4_TEMP1_Pin GPIO_PIN_3
#define ADC1_IN4_TEMP1_GPIO_Port GPIOA
#define RLY_LE_Pin GPIO_PIN_4
#define RLY_LE_GPIO_Port GPIOA
#define RLY_SPI1_SCK_Pin GPIO_PIN_5
#define RLY_SPI1_SCK_GPIO_Port GPIOA
#define RLY_OE_Pin GPIO_PIN_6
#define RLY_OE_GPIO_Port GPIOA
#define RLY_SPI1_MOSI_Pin GPIO_PIN_7
#define RLY_SPI1_MOSI_GPIO_Port GPIOA
#define ADC1_IN_15_TEMP2_Pin GPIO_PIN_0
#define ADC1_IN_15_TEMP2_GPIO_Port GPIOB
#define GPIO_EXT_IN2_Pin GPIO_PIN_8
#define GPIO_EXT_IN2_GPIO_Port GPIOA
#define GPIO_EXT_IN1_Pin GPIO_PIN_9
#define GPIO_EXT_IN1_GPIO_Port GPIOA
#define NC_Pin GPIO_PIN_3
#define NC_GPIO_Port GPIOB
#define INT_UI_Pin GPIO_PIN_4
#define INT_UI_GPIO_Port GPIOB

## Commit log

2023-08-18 Add mainboard design files
    [mainboard.kicad_pcb, mainboard.kicad_sch, relay_driver.kicad_sch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]
2023-08-19 Add UI board design
    [ui_board.kicad_pcb, ui_board.kicad_sch]
2023-08-19 Add links to interactive bom
2023-08-19 Add power supply board and minor improvements
    [power_supply.kicad_pcb, power_supply.kicad_sch, ui_board.kicad_sch]
2023-08-19 Add front and rear panels
    [front_panel.kicad_pcb, front_panel.kicad_sch, rear_panel.kicad_pcb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]
2023-08-19 Move rear panel files
    [rear_panel.kicad_pcb, rear_panel.kicad_sch]
2024-04-12 Update power supply KiCAD project to v8 and fix incorrect R1 resistor value
    [power_supply.kicad_pcb, power_supply.kicad_sch]
2024-05-17 Update README.md
    Add note regarding the necessity of an external EMI filter.
2025-05-05 Update to Kicad v9, new power supply board and other modifications
    [front_panel.kicad_pcb, front_panel.kicad_sch, mainboard.kicad_pcb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]
2025-10-29 Update README with power supply design note
    Added a note about the power supply design changes and documentation discrepancies.
2025-11-02 Fix typos and enhance safety warnings in README
    Updated warnings and notes regarding power supply safety and design changes.

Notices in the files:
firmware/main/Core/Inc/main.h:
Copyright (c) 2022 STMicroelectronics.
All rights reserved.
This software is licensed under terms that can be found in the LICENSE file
